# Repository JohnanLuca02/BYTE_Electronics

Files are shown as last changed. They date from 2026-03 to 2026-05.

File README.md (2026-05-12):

# BYTE_Electronics
Repository for everything concerning the electronics (PCB, Electrical schemes, BOM, ...) of the robot dog project of the AiTeam called BYTE.

**READ BEFORE STARTING TO WORK**

**Github workflow:**

*ALWAYS* work on your own branch
1) Check that you're in the correct branch:
   - git branch --all
       - if your branch is highlated in *green*, you can go to step 2)
       - if your branch is highlated in *red*, follow the next steps:
           - git fetch --all
           - git checkout [*name of your branch*]
     
2) Once you're in the right branch, *always* start pulling the changes:
   - git pull 
3) Often save your progress:
   - git add .
   - git commit -m "[*Message describing the changes made*]"
4) At the end of your session, ore once you're happy with your work, push your progress on the repo:
   - git push
  
**FOR EASYEDA2KICAD PLUG-IN**

easyeda2kicad --full --lcsc_id [LCSC CODE] --output .

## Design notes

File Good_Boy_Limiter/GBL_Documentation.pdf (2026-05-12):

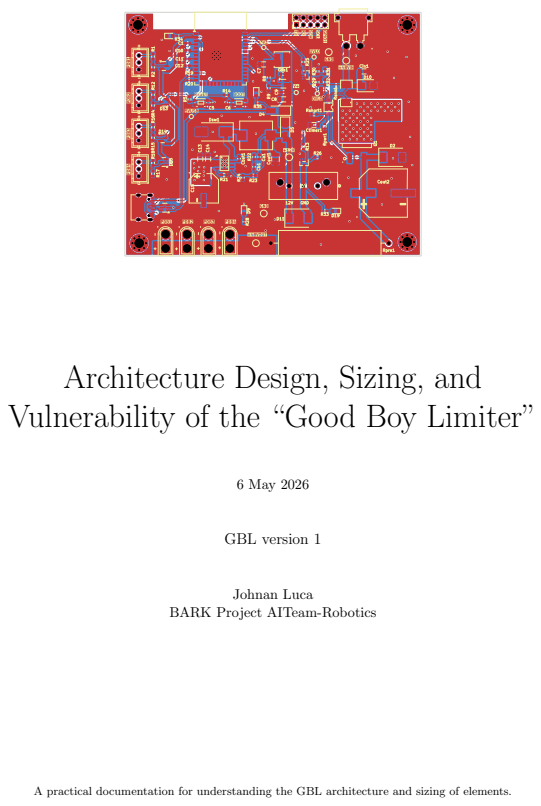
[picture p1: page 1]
6 May 2026; GBL version 1; Johnan Luca

Architecture Design, Sizing, and
Vulnerability of the “Good Boy Limiter”

BARK Project AITeam-Robotics

A practical documentation for understanding the GBL architecture and sizing of elements.

## Contents

1 Abstract and System Overview | 2
2 Power Architecture: Relay Versus Solid-State | 2
3 Analysis and Sizing of the Pre-Charge Dynamics | 3
4 In-Rush Controller (LM5069) Analysis and Sizing | 4

4.4 Power Limit Sizing (PF ET(LIM)

5 Thermal Management and MOSFET Safe Operating Area (SOA) | 7
6 Thermal Limitations: Analyzing the 50 Ω Power Resistor | 7
7 Control Logic, System Security, and the Software Timeout | 8
8 Auxiliary Power Supply: LM5013 DC-DC Converter | 9
9 Power Supply Logic and 3V3 Selector (SY8120B and Case Control) | 10
10 LEDs | 12
11 Conclusion and Recommendations | 13
12 Next Steps for future iterations | 13
13 Annexes | 13
14 References | 17

## 1 Abstract and System Overview

The design of high-power DC distribution networks frequently encounters the engineering challenge of managing massive capacitive loads during the initial charging phase. The “Good Boy Limiter” (GBL) represents an hybrid power management and in-rush current control architecture specifically designed to address these challenges within a 48 V DC ecosystem.
The main problem addressed by the GBL architecture is the safe charge and continuous operation of a downstream load characterized by a really large input capacitance. Specifically, the system must interface with a bulk bus capacitance (Ctot) of 7920 µF, which is physically realized through a distributed 4 × 6 matrix of 330 µF electrolytic capacitors. Furthermore, the system is designed to support a substantial nominal operating current of 260 A, although it is currently constrained to a 120 A limit for safety reasons.
Attempting to directly connect a 48 V stiff voltage source to an uncharged 7920 µF capacitor bank results in an instantaneous ”in-rush” current theoretically limited only by the Equivalent Series Resistance (ESR) of the capacitors and the parasitic inductance of the interconnecting cables. In practical terms, this transient current can easily exceed several thousands of amperes. Such catastrophic current spikes induce severe electromagnetic interference (EMI), trigger upstream power supply overcurrent protections, and instantly weld the contacts of mechanical relays due to localized plasma arcing.
To resolve these conflicting requirements, the GBL employs a mixed relay/solid-state architecture. A heavy-duty mechanical external relay (actuated via a 12 V coil) serves as the primary conduction path during nominal steady-state operation. In parallel, a highly controlled solid-state pre-charge circuit, orchestrated by the Texas Instruments LM5069-2 hot-swap controller and an STMicroelectronics STB15810 MOSFET, governs the initial energization phase.
This report provides an exhaustive analysis of the pre-charge dynamics, focusing on the mathematical sizing of the LM5069-2 control parameters. It critically examines the thermal paradigm shift achieved by the inclusion of a series limiting resistor, assesses the Safe Operating Area (SOA) of the selected MOSFET, and documents the role of the ESP32-S3 microcontroller in mitigating topological safety vulnerabilities.

## 2 Power Architecture: Relay Versus Solid-State

High-current DC power distribution systems inherently suffer from the physical limitations of their switching elements. The architectural decision to utilize a hybrid system in the Good Boy Limiter is grounded in fundamental power dissipation physics.

### 2.1 The Limitations of Pure Solid-State Switching

In a hypothetical pure solid-state architecture managing the full 260 A nominal current, the conduction losses would be to high. Even utilizing state-of-the-art power MOSFETs exhibiting an ultra-low drain-to-source on-resistance (RDS(on)

) of 1 mΩ, the continuous power dissipation (Ploss) would be substantial. According to Joule’s law:

Ploss = I

2 × RDS(on) = (260 A)² × 0.001 Ω = 67.6 W | (1)

Dissipating 67.6 W of pure thermal energy on a printed circuit board (PCB) requires massive copper planes, extensive thermal via arrays, large extruded aluminum heatsinks, and mandatory active forced-air cooling. This increases volumetric footprint, acoustic noise, and overall system failure rates.

### 2.2 The Limitations of Pure Mechanical Switching

Vice-versa, a purely mechanical relay architecture offers micro-ohm contact resistance, virtually eliminating steady-state thermal dissipation. However, mechanical relays are physically incapable of closing into an uncharged 7920 µF capacitive bus at 48 V. As the relay contacts physically approach one another during closure, the dielectric breakdown voltage of the microscopic air gap is exceeded. This initiates a high-energy plasma arc. The thousands of amperes of in-rush current flowing through this plasma instantly melt the contact plating, leading to contact welding and permanent failure of the relay.

### 2.3 The Hybrid Resolution

The GBL architecture resolves this dichotomy via a parallel power path topology:

- The Solid-State Pre-Charge Path: Engaged first, this path utilizes a series-pass Nchannel MOSFET (STMicroelectronics STB15810) and a 50 Ω wirewound power resistor (EWWR0010J50R0T9) to strictly limit the transient charging current. The capacitors are charged safely over a calculated time domain.
- The Main Relay Path: Engaged only when the ESP32-S3 microcontroller verifies that the bus voltage has reached the nominal source voltage. Because the voltage differential (∆V ) across the relay contacts is near zero, the corresponding current during closure is zero. Closing the relay under this Zero-Voltage Switching (ZVS) entirely eliminates arcing, preserving contact longevity. Once the relay is closed, the solid-state path is disabled.

## 3 Analysis and Sizing of the Pre-Charge Dynamics

The pre-charge network is mathematically modeled as a first-order ideal RC circuit. The primary system parameters dictate a DC source voltage (VIN ) of 48 V, a total bus capacitance (Ctot) of 7920 µF, and a physical current-limiting series resistance (Rpre) of 50 Ω.

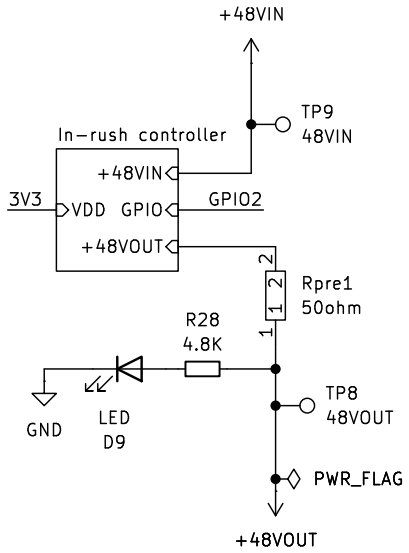
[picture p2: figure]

Figure 1: Detail of the solid-state pre-charge topology. The 50 Ω resistor RP RE1 dominates the branch impedance, physically limiting the maximum current to 0.96 A regardless of the state of the LM5069 controller.

### 3.1 Peak In-Rush Current Constraint

The theoretical peak current (Ipeak) occurs instantaneously at t = 0, assuming the capacitor bank is fully discharged (VC = 0 V). The peak current is defined by Ohm’s Law across the series resistor:

Ipeak =

VIN

Rpre

=

48 V
50 Ω = 0.96 A | (2)

By actively restricting the peak current to a mere 0.96 A, the GBL architecture completely eliminates the stress on the upstream 48 V power supply. The upstream source perceives the startup event as a negligible, highly controlled 46 W load rather than a multi-kilowatt short circuit.

### 3.2 Time Constant and RC Charging Profile

The exponential voltage charging profile of the capacitor bank is governed by the RC time constant (τ ), which dictates the temporal response of the circuit:

τ = Rpre1 × Ctot = 50 Ω × 0.00792 F = 0.396 s | (3)

The bus voltage as a function of time, VC(t), is defined by the standard step-response differential equation solution:
VC(t) = VIN
1 − e

−t
τ

= 48
1 − e

−t

0.396
(4)

In standard engineering practice, a capacitor is considered functionally charged at 3τ (95.0% of VIN ) and fully charged at 5τ (99.3% of VIN ).
We can calculate the exact time required to reach the 95% threshold (45.6 V):
t95% = 3 × τ = 3 × 0.396 s = 1.188 s | (5)

Furthermore, the time required to reach the 99% threshold (47.5 V):

t99% = 5 × τ = 5 × 0.396 s = 1.980 s | (6)

These timing calculations define the minimum operational window required before the ESP32-S3 firmware can safely command the main mechanical relay to close. Actuating the relay before 1.188 s would risk residual arcing due to a significant remaining voltage differential.

### 3.3 Energy Transfer Thermodynamics

The total energy transferred from the 48 V source to fully charge the capacitor bank is derived from the energy stored in the electric field of the capacitors:

Ecap =

1
2

CtotV

2
IN =

1
2
× 0.00792 F × (48 V)² = 9.1238 J | (7)

A fundamental principle of thermodynamics in RC charging circuits dictates that an exactly equal amount of energy is dissipated as heat within the resistive elements of the charging path. Therefore, regardless of the charging speed, exactly 9.12 J of thermal energy is deposited into the 50 Ω wire-wound resistor during every startup sequence. This will be critically analyzed in Section 6.

## 4 In-Rush Controller (LM5069) Analysis and Sizing

The Texas Instruments LM5069-2 operates as the gate driver and primary hardware safety controller for the solid-state pre-charge branch.
The following subsections detail the mathematical sizing of its internal thresholds.

### 4.1 Undervoltage Lockout (UVLO) Sizing

The UVLO pin ensures the controller only activates when the input bus is stable and possesses sufficient voltage to properly drive the downstream loads. The LM5069 possesses a precise internal comparator with an enable threshold of 2.5 V. To prevent rapid ON/OFF oscillation (chattering) when the input voltage fluctuates near the threshold, the IC utilizes an internal 21 µA current source to provide a programmable hysteresis.
The GBL schematic defines a dedicated UVLO resistive divider utilizing R25 = 143 kΩ as the top resistor and R30 = 10 kΩ as the bottom resistor connected to ground.
The rising input threshold voltage (VUVLO RISE) at which the controller enables the pre-charge sequence is calculated as:

VUVLO RISE = VREF ×

R25 + R30

R30

= 2.5 V ×

143 kΩ + 10 kΩ
10 kΩ | = 38.25 V | (8)

Once the input voltage exceeds 38.25 V, the 21 µA internal current source activates and flows out of the UVLO pin, through the bottom resistor R30, effectively raising the pin voltage. This creates the hysteresis voltage (VUVLO HYS), which is dictated by the current source acting upon the top resistor R25:

VUVLO HYS = IHY S × R25 = 21 µA × 143 kΩ = 3.003 V | (9)

The falling threshold voltage (VUVLO FALL), where the controller will abort the sequence due to a sagging input bus, is therefore:

VUVLO FALL = VUVLO RISE − VUVLO HYS = 38.25 V − 3.003 V = 35.247 V | (10)

Therefore, the pre-charge sequence is hardware-locked until the input voltage is a steady 38.25 V, and it possesses a robust 3 V noise margin before shutting down at 35.24 V.

### 4.2 Overvoltage Lockout (OVLO) Sizing

Similarly, the OVLO pin protects the downstream systems from catastrophic input voltage surges, such as load-dump events or incorrect power supply connections. To maintain precise and independent control over the overvoltage threshold, the GBL schematic utilizes a separate, dedicated divider string: R32 = 210 kΩ as the top resistor and R29 = 10 kΩ as the bottom resistor.
The rising overvoltage cutoff threshold (VOVLO RISE) is calculated using the same 2.5 V internal reference:

VOVLO RISE = VREF ×

R32 + R29

R29

= 2.5 V ×

210 kΩ + 10 kΩ
10 kΩ | = 55.00 V | (11)

The OVLO pin also features a 21 µA hysteresis current source. The hysteresis voltage is:

VOVLO HYS = IHY S × R32 = 21 µA × 210 kΩ = 4.410 V | (12)

The falling recovery threshold (VOVLO FALL), where the system permits operation to resume after an overvoltage event clears, is:

VOVLO FALL = VOVLO RISE − VOVLO HYS = 55.00 V − 4.41 V = 50.59 V | (13)

The hardware overvoltage cutoff is situated at 55.00 V. This provides adequate operational margin above the nominal 48 V state, while strictly protecting downstream components from transient degradation.

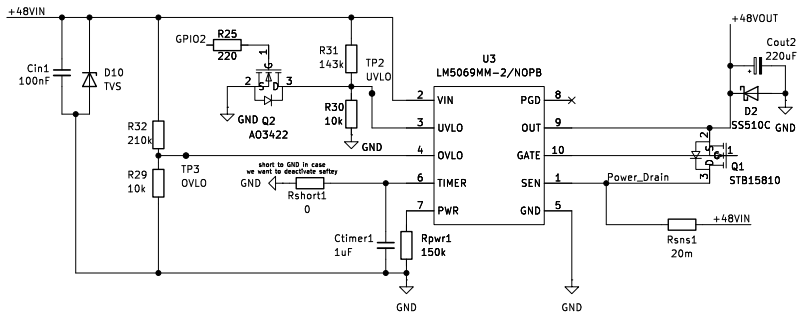
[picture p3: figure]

Figure 2: Schematic of the independent resistive dividers for the undervoltage (R25, R30) and overvoltage (R32, R29) thresholds. The use of two separate networks ensures clear and independent hysteresis for the operating windows at 38.25 V and 55.00 V.

### 4.3 Hardware Current Limit (ILIM ) and Rsns1 Sizing

The standard operational mode of the LM5069 relies on sensing the voltage drop across a precision shunt resistor (RSENS1) placed directly between the VIN and SENSE pins. If the load current increases such that the voltage across the sense resistor reaches 55 mV, the LM5069 limits the current by dynamically adjusting the MOSFET gate voltage.
In the GBL design, a value for RSENS1 = 20 mΩ is utilized. The absolute hardware current limit is established mathematically as:

ILIM =

VSNS(th)

RSENS1

=

55 mV
20 mΩ = 2.75 A | (14)

### 4.4 Power Limit Sizing (PF ET(LIM))

To protect the external MOSFET from violating its Safe Operating Area (SOA) during linear mode regulation, the LM5069 allows the maximum allowable power dissipation of the FET to be programmed via the PWR pin. The LM5069 monitors the VDS of the MOSFET by comparing the SENSE pin and the OUT pin.
This limit is set using an external resistor (RPW R1) connected to the PWR pin. The schematic indicates RPW R1 = 150 kΩ.
The formula correlating the programmable power limit to the sense resistor and the PWR resistor is provided by Texas Instruments as:

PF ET(LIM) =

RPW R1
1.25 × 10⁵ × RSENS1

=

150, 000 Ω
1.25 × 10⁵ × 0.020 Ω = 60 W | (15)

The hardware is theoretically configured to throttle the MOSFET gate if it detects the MOSFET is dissipating more than 60 W of heat. However, the presence of the 50 Ω resistor ensures the MOSFET never dissipates anywhere near 60 W. This will be proven in Section 5.

### 4.5 Fault Timer Duration (tF AULT )

The fault timeout allows the system to ride through brief, acceptable transient over-currents without nuisance tripping, but ensures the MOSFET is definitively shut down if a fault persists long enough to threaten the system. The timing is dictated by an external capacitor CT IMER1 = 1 µF connected to the TIMER pin.
The typical duration before a fault is declared and the gate is pulled low is defined by the equation:

tF AULT = CT IMER1 ×

vtimer,typ

itimer,typ

= 1 × 10⁻⁶ F × 4.7 × 10⁴ = 0.047 s = 47 ms (16)

The specific LM5069-2 variant utilized in this design features an Auto-Retry mechanism. If the controller were to enter a current or power limit regulation state for longer than the 47 ms timer, the device would shut down the MOSFET, run through an extended internal cool-down cycle (dictated by the same capacitor), and then attempt to restart the process automatically. However, as established, the controller is physically prevented from ever entering the regulation state due to the 50 Ω resistor.

## 5 Thermal Management and MOSFET Safe Operating Area

## (SOA)

The defining architectural characteristic of the GBL pre-charge circuit is the intentional shifting of the massive thermal dissipation burden away from the semiconductor lattice of the STB15810 MOSFET and onto the robust, passive wirewound resistor.

### 5.1 The STB15810 MOSFET in Deep Saturation

In the Good Boy Limiter architecture, the presence of the 50 Ω resistor physically restricts the maximum current to 0.96 A. Because 0.96 A is vastly lower than the LM5069’s 2.75 A current regulation threshold, the LM5069’s internal high-side charge pump continues to pump unabated. It fully enhances the MOSFET gate, raising VGS to its maximum value (typically 10 V to 12 V above the source). This pushes the MOSFET completely out of the linear region and deep into the ohmic region (saturation).
The STB15810 is a heavily over-specified 100 V, 110 A device utilizing advanced STripFET™ F7 trench gate technology, boasting an ultra-low RDS(on) of 3.9 mΩ typical and 7 mΩ absolute maximum.
Assuming the worst-case scenario at maximum operating junction temperature where RDS(on) = 7 mΩ, the peak power dissipated by the MOSFET during the absolute highest current flow of the pre-charge phase (0.96 A at t = 0) is simply calculated using Joule’s law for a pure resistance:

PMOSF ET(peak) = I

2

peak × RDS(on) = (0.96 A)² × 0.007 Ω = 0.0064 W = 6.4 mW (17)

Dissipating a mere 6.4 mW means the STB15810 will experience absolutely zero measurable thermal rise above ambient temperature. The device remains entirely safe, utterly immune to the Spirito effect, and operates infinitely deep within the safest bounds of its DC SOA curve. From the perspective of thermal stress, the MOSFET acts as a perfect wire.

## 6 Thermal Limitations: Analyzing the 50 Ω Power Resistor

Because the MOSFET acts as a near-perfect conductor, the 50 Ω wirewound resistor assumes basically 100% of the thermal load during the pre-charge event.
During the exact moment of turn-on (t = 0), the capacitor bank acts as a short circuit, meaning the entire 48 V source is dropped across the resistor. The instantaneous peak power dissipation is:

PRESIST OR(peak) =

V

2
IN
Rpre

=

(48 V)²
50 Ω = 46.08 W | (18)

The selected component, EWWR0010J50R0T9, is a wirewound power resistor rated for 10 W of continuous steady-state power. Operating a 10 W rated resistor at 46.08 W could appears as a design error; however, it is permissible because pre-charging is a highly transient pulse event, not a steady-state condition.
As calculated in Equation (7), the total energy deposited into the resistor over the entire 1.5 to 2.0 second charging curve is strictly bounded to 9.12 J. Wirewound resistors are specifically constructed by winding a resistive alloy wire around a dense ceramic core. This ceramic core possesses a significant thermal mass. During a short 2-second pulse, the heating is largely adiabatic, the energy is absorbed directly into the thermal mass of the ceramic core, resulting in a moderate, entirely safe transient temperature rise.
The critical operational limitation here is duty cycle: the system must not be commanded to repeatedly toggle the pre-charge sequence in rapid succession. Sufficient cool-down time (several seconds) must be enforced by the ESP32 software to allow the ceramic core to shed this thermal energy to the ambient environment.

## 7 Control Logic, System Security, and the Software Timeout

While the delegation of the current-limiting role to a passive 50 Ω resistor safely protects the MOSFET, it simultaneously creates a critical vulnerability within the hardware protection layers of the LM5069. This vulnerability necessitates the implementation of an active software safety supervisory system via the ESP32-S3 microcontroller.

### 7.1 The “Hardware Blind Spot” during a Hard Short

Consider a catastrophic operational scenario: a dead short circuit directly to ground exists on the 48 V output bus (e.g., a crushed cable or a failed downstream component) before the system is turned on.
When the ESP32 initiates the pre-charge sequence, the 50 Ω resistor performs its physical duty and limits the fault current:

Ifault =

48 V
50 Ω + 0.020 Ω + 0.007 Ω
≈ 0.96 A | (19)

Because the fault current (0.96 A) is significantly lower than the LM5069 hardware current limit threshold (2.75 A), the LM5069 internal current comparator is never triggered. Furthermore, because the 50 Ω resistor is dropping nearly the entire 48 V, the voltage at the SENSE pin is roughly 0 V, and the VDS across the MOSFET is negligible (a few millivolts). Consequently, the power limit comparator (PLIM = 60 W) is also completely blind to the fault.
The Catastrophic Result: The LM5069 views the dead short circuit as a completely normal, healthy operating condition. The internal 47 ms fault timer (CT IMER) never begins counting. The hardware safety system will remain engaged indefinitely, forcing the 10 W wirewound resistor to continuously dissipate 46.08 W. Within a matter of seconds, the resistor will violently exceed its thermal degradation limits, resulting in extreme overheating, outgassing, potential ignition of surrounding components, and ultimately an open-circuit failure.

### 7.2 The ESP32-S3 Software Timeout Mitigation

To permanently resolve this dangerous topological vulnerability, the ESP32-S3 microcontroller is tasked with monitoring the dynamic health of the pre-charge process via the dedicated Voltage Sensing Modules.

Figure 3: Schematic diagram of the V Sensing modules used by the ESP32 to read the bus voltage. Note the resistor dividers connected to the BAT54S diodes, which are essential for protecting the microcontroller’s ADC inputs from transient overvoltages.

The ESP32 reads the intermediate bus voltage via a resistor divider string (R14 = 10 kΩ, etc.). These inputs are aggressively protected by dual BAT54S Schottky clamping diodes, which prevent the microcontroller’s sensitive ADC pins from exceeding the 3.3 V logic supply limit even during severe transients.
The ESP32 firmware must be programmed to implement a strict, non-blocking state-machine timeout logic:
1. Initiation: The ESP32 asserts the LM5069 EN/UVLO pin HIGH via a GPIO pin to begin the pre-charge sequence. Simultaneously, it initializes an internal hardware software timer (t = 0).
2. Continuous Monitoring: The ADC continuously samples the bus voltage (Vbus) at a high frequency.
3. Success Condition: If Vbus successfully exhibits the standard RC charging curve and exceeds 45 V (approximately 3τ ) within a 1.5 to 2.0 second window, the pre-charge is deemed successful. The ESP32 then commands the main 12 V mechanical relay to close, routing the 260 A capability to the load. Once the relay confirms closure, the solid-state branch is deactivated.
4. Timeout Failure Condition (The Critical Mitigation): If Vbus fails to rise above a minimum safety threshold within 3.0 seconds (a “Timeout of Security”), it is definitive proof of a downstream fault or short circuit absorbing the charge current. The ESP32 must immediately and unconditionally force the EN/UVLO pin LOW. This action forcefully shuts down the LM5069, halting the current flow and saving the 50 Ω resistor from thermal destruction.

This software-defined safety boundary bridges the gap left by the hardware topology, ensuring full system resilience against all modes of failure.

## 8 Auxiliary Power Supply: LM5013 DC-DC Converter

To drive the heavy inductive coil of the main mechanical relay and provide logic-level power to the digital supervision systems, the GBL integrates a high-voltage auxiliary step-down (buck) converter based on the Texas Instruments LM5013DDAR.
The LM5013 steps the primary 48 V distribution bus down to an intermediate 12 V rail. The converter is capable of handling inputs up to 100 V, providing massive immunity against 48 V bus ringing and transients. It operates utilizing a Constant On-Time (COT) architecture. COT control provides exceptional transient load response (essential when slamming a heavy relay coil) and entirely eliminates the need for complex external loop compensation networks (type II or type III compensators), simplifying the PCB layout.

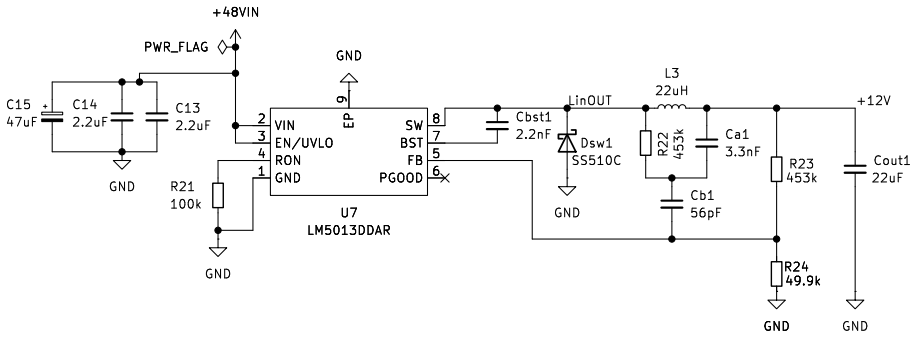
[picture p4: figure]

Figure 4: Topology of the LM5013 step-down converter. The main components are: the 22 µH inductor L3, the bypass diode Dsw1 (SS510C), and the R23/R24 feedback network for precise regulation of the 12 V output.

### 8.1 Feedback Sizing for the 12 V Rail

The output voltage is programmed via a precision resistor divider feeding back into the FB pin. The highly precise internal bandgap reference voltage of the LM5013 is exactly VREF = 1.2 V. The schematic defines the top feedback resistor as RF B1(R23) = 453 kΩ and the bottom resistor connected to ground as RF B2(R24) = 49.9 kΩ.
The nominal output voltage is mathematically derived as:

VOUT = VREF ×

1 +

RF B1

RF B2

= 1.2 V ×
1 +

453 kΩ

49.9 kΩ
(20)
VOUT = 1.2 V × (1 + 9.078) = 1.2 V × 10.078 = 12.09 V | (21)

### 8.2 Core Buck Components and Filtering

The power stage utilizes a low-DCR inductor L3 = 22 µH and an SS510C Schottky freewheeling diode (DSW1). The presence of the external Schottky diode is mandatory for this nonsynchronous topology to provide a path for the inductor current during the MOSFET off-time. The Constant On-Time programming resistor is RON (R21) = 100 kΩ, establishing the nominal switching frequency.
Input voltage ripple and filtering are aggressively handled by dual low-ESR 2.2 µF ceramic capacitors (C13, C14) plus a larger 47 µF bulk capacitor (C15). This network attenuates highfrequency switching noise, preventing the buck converter from injecting harmonic distortions back into the main 48 V distribution bus. A secondary step-down stage (utilizing the SY8120B buck converter) subsequently drops this intermediate 12 V to a highly regulated 3.3 V rail to power the ESP32-S3 microcontroller and its associated sensitive analog peripherals.

## 9 Power Supply Logic and 3V3 Selector (SY8120B and Case Control)

The ESP32-S3 and the analog logic arrays require a stable, low-noise 3.3V power rail. To ensure the microcontroller remains active and functional under multiple operating conditions, such as during initial programming via a PC (USB power), standalone operation from external logic batteries, or standard nominal operation connected to the main 48V bus, a specialized “3V3 Selector” architecture is implemented.

Figure 5: Schematic diagram of the “3V3 Selector” module based on the SY8120B synchronous buck converter. Note the OR-gate diode configurations (D4 and D5) for transparent switching between the USB power supply and the 12V bus, and the R10/R11 feedback divider for precise regulation to 3.3V.

### 9.1 Power Source OR-ing Network and Operational Scenarios

The input to the 3.3V regulation stage (Vin) is sourced dynamically via a passive diode OR-ing network. This network prevents reverse-current back-feeding and allows the system to autonomously draw power from the most viable source without logic interruption. The system relies on two SS34 Schottky diodes (D4 and D5) which feature a low forward voltage drop (Vf ≈ 0.4V at nominal logic currents).The architecture supports three distinct operational scenarios:

- Case 1: PC Configuration Only (No Main Battery Connected).
When the GBL is completely disconnected from the 48V high-voltage bus (no XT30 battery connected) and plugged into a host PC via the USB-C connector, the cable supplies +5VUSB. Diode D4 becomes forward-biased. The internal node Vin reaches approximately 4.6V (5V − Vf(D4)). Because the SY8120B regulator has a minimum operational input threshold of 4.0V, it successfully activates, generating the 3.3V rail. This allows the ESP32 to be programmed, flashed, or debugged safely on a workbench without exposing the user to high-voltage hazards.
- Case 2: Main Battery / 48V Bus Nominally Connected.
During standard operation, the main power source (e.g., a 48V battery pack) is connected to the XT30 connectors (CN1). The upstream LM5013 buck converter actively steps the 48V down to the intermediate +12V rail. This 12V potential reaches the anode of diode D5. D5 becomes forward-biased, pulling the Vin node to approximately 11.6V (12V − Vf(D5)). The SY8120B easily accepts this input (rated up to 18V maximum) and drops it to 3.3V.
- Case 3: Both Main Battery and PC USB Connected.
This is the most critical cross-power scenario. If a user connects the USB-C cable for telemetry while the 48V bus is fully live, the OR-ing network automatically resolves the power conflict. The anode of D5 sits at +12V, while the anode of D4 sits at +5VUSB. Because the cathodes of both diodes are tied together at the Vin node, D5 will strongly conduct and pull the Vin node up to 11.6V. Consequently, the +11.6V at the cathode of

D4 is significantly higher than the +5V at its anode. Diode D4 becomes heavily reversebiased and stops conducting completely.
Result: The logic array draws zero power from the host PC’s USB port, protecting the laptop’s motherboard and ensuring the ESP32 is powered exclusively by the main battery line, while keeping the communication lines active for interfacing the MCU.

### 9.2 SY8120B Synchronous Buck Converter Sizing

Unlike the LM5013, the SY8120B is a synchronous buck converter. It integrates both the high-side and low-side switching MOSFETs internally. These internal switches boast very low RDS(on) characteristics (145 mΩ top / 135 mΩ bottom), minimizing conduction losses and entirely eliminating the need for an external Schottky freewheeling diode.
The output voltage is programmed by the external resistor divider connected to the feedback (FB) pin. The internal bandgap reference voltage of the SY8120B is VREF = 0.6V.Utilizing the designated top resistor R10 = 100 kΩ and the bottom resistor R11 = 22 kΩ, the nominal output voltage is derived using the standard feedback formula:

VOUT = VREF ×

1 +

R10

R11
= 0.6 V ×
1 +

100 kΩ

22 kΩ
= 3.327 V | (22)

The calculated 3.327V output provides a regulated logic-level rail for the ESP32-S3. An external pull-up resistor R8 = 100 kΩ connects the EN (Enable) pin directly to the input voltage node (Vin), ensuring the regulator automatically initiates switching the millisecond a valid power source (USB or Battery) is applied via the OR-ing networkr.

## 10 LEDs

### 10.1 LED’s Resistors Sizing

To light an LED from a power rail, you simply place the LED in series with a current-limiting resistor across the rail and ground. You must calculate the correct resistance (R) using Ohm’s Law for preventing the LED to burn out:

R =

Vrail − Vf
If

(23)

- Vrail: The voltage of your power rail (e.g., 3.3V, 5V, 12V).
- Vf : The Forward Voltage of the LED (typically 1.8V for Red, 3.2V for Blue/White).
- If : The Forward Current you want (typically 2mA to 20mA).

### 10.2 GBL’s LEDs Color Code

- RED: +48V Pre-charge power rail is ON
- YELLOW: +3V3 power rail is ON
- GREEN: Relay is closed
- BLUE: +5USB power rail is ON
- ORANGE: +12V rail is ON

## 11 Conclusion and Recommendations

The “Good Boy Limiter” architecture represents a possible solution to the challenge of managing massive capacitive loads in high-current DC environments. By utilizing a mixed-topology parallel design, it combines the zero-loss continuous conduction capabilities of a mechanical relay with the non-destructive startup characteristics of a solid-state pre-charge circuit.
The sizing of the Texas Instruments LM5069-2 components is mathematically made. The selected resistor dividers establish 38.25 V and 55.00 V operational voltage lockouts, ensuring the system only operates within a safe 48 V nominal window. The absolute hardware current limit is determinate by RSENS1 at 2.75 A.
Furthermore, the decision to utilize a 50 Ω series power resistor shields the STB15810 MOS-FET from the destructive Safe Operating Area (SOA) stresses typically associated with linearmode hot-swap events. By pushing the MOSFET deep into saturation, its thermal load is reduced to a negligible 6.4 mW, transferring the energy entirely to the adiabatic mass of the wirewound resistor.
Therefore, it is an absolute, critical project requirement to implement the 3.0 second Software Safety Timeout logic on the ESP32-S3. Without this digital supervisor actively pulling the LM5069 EN pin low upon a failure to charge, the 10 W pre-charge resistor will face inevitable and thermal failure under a continuous 46 W fault load.

## 12 Next Steps for future iterations

- Sizing optimization
- Design a better Solid-State branch

– Better LM5069 safety features

– Charge pump (at least to 48V + VGS(th)

) with VGS = 48V SS

– Gate driver with 48V + VGS(th) and boost converter

- Routing optimization

## 13 Annexes

Complete GBL e-scheme:

# H4 H3 GND

10k 1

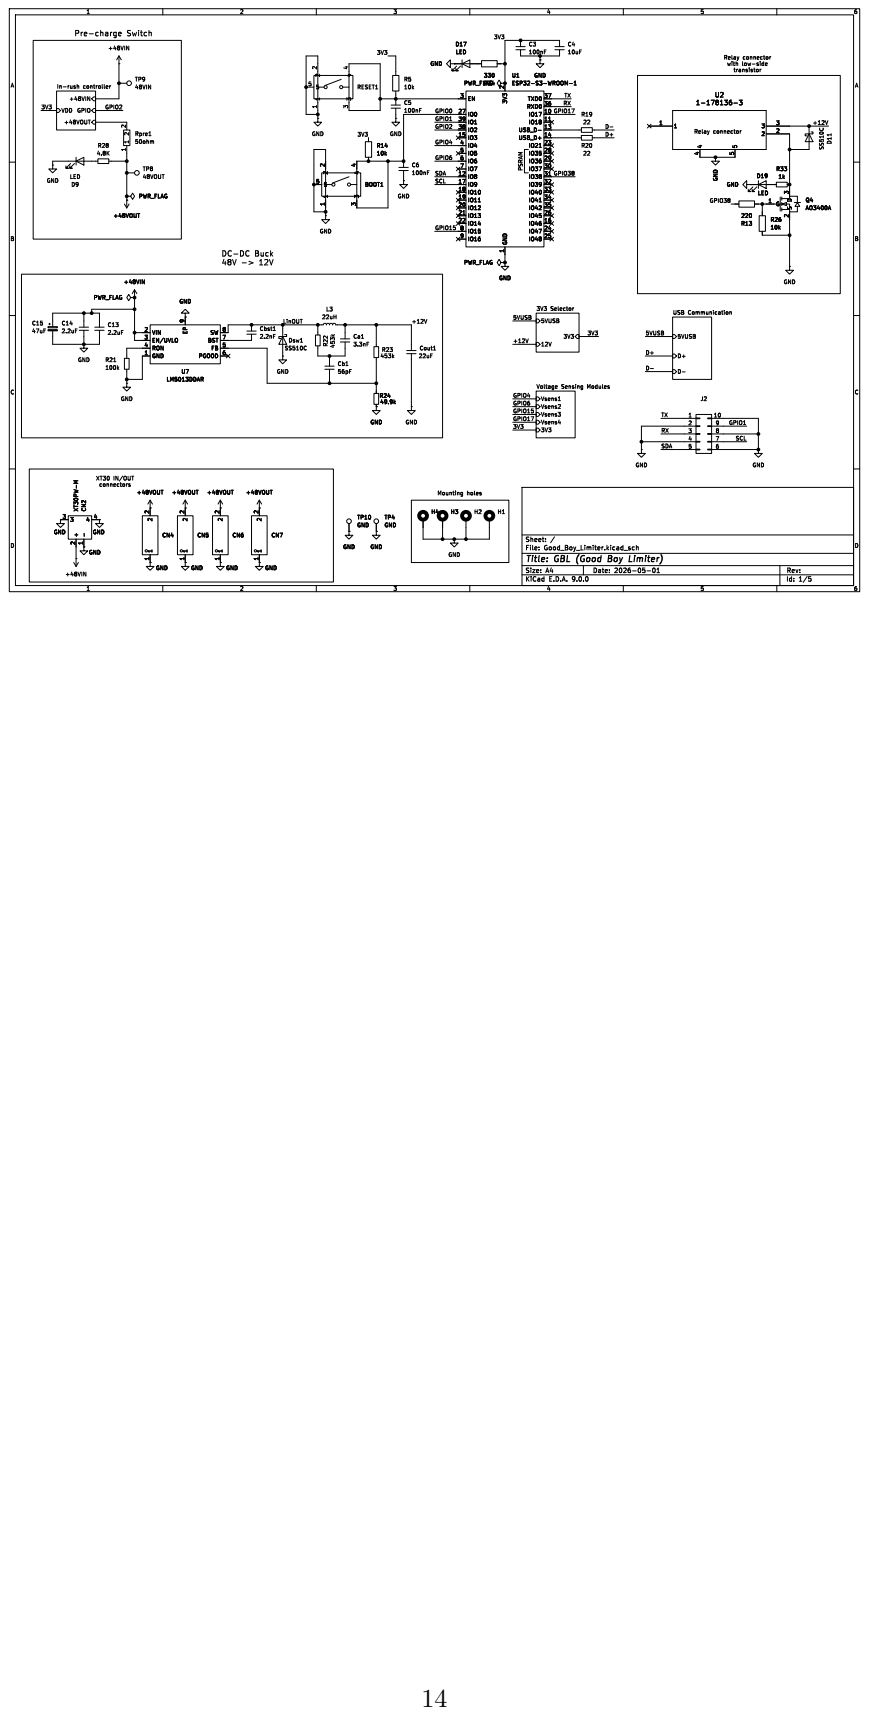
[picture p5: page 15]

transistor DC-DC Buck

3V3 Voltage Sensing Modules VDD

9 SW 8 BST 7 FB 5 PGOOD 6 +48VOUT PWR_FLAG

9 SW 8 BST 7 FB 5 PGOOD 6 U7

Id: 1/5 Title: GBL (Good Boy Limiter) File: Good_Boy_Limiter.kicad_sch Sheet: / Vsens3 Vsens4 Vsens1 Vsens2

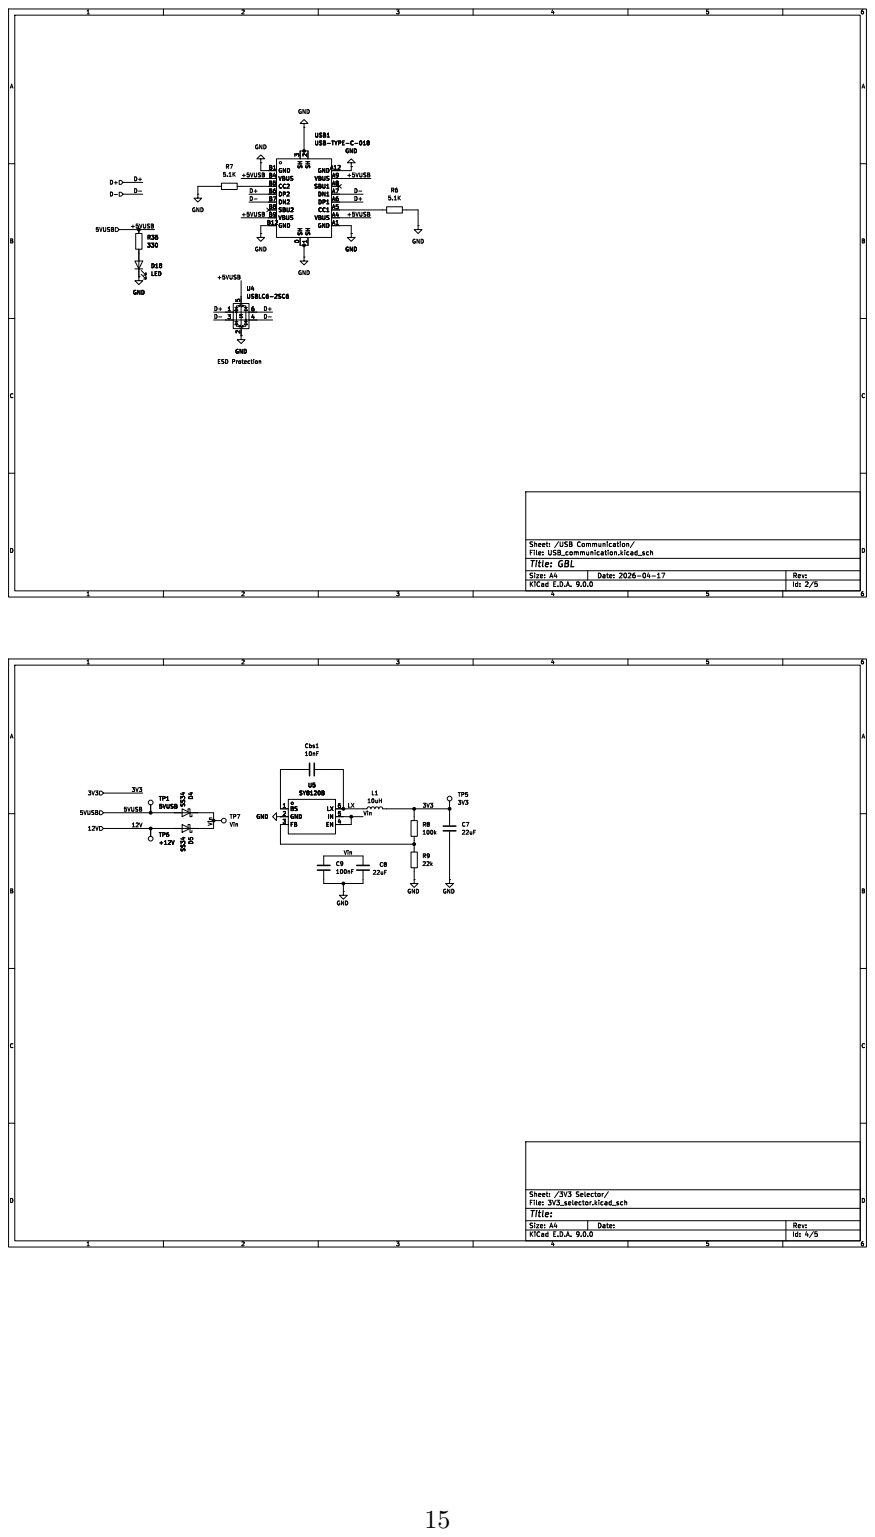
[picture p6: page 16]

1 GNDA12 VBUS A9 SBU1 A8 DN1 A7 DP1 A6 CC1 A5 VBUS A4 GND A1 USB1 USB-TYPE-C-018 GND GND GND GND

File: USB_communication.kicad_sch Sheet: /USB Communication/ GND GND GND GND

Id: 4/5 Title: File: 3V3_selector.kicad_sch Sheet: /3V3 Selector/ L1

# 3 U11 B3B-XH-A C11

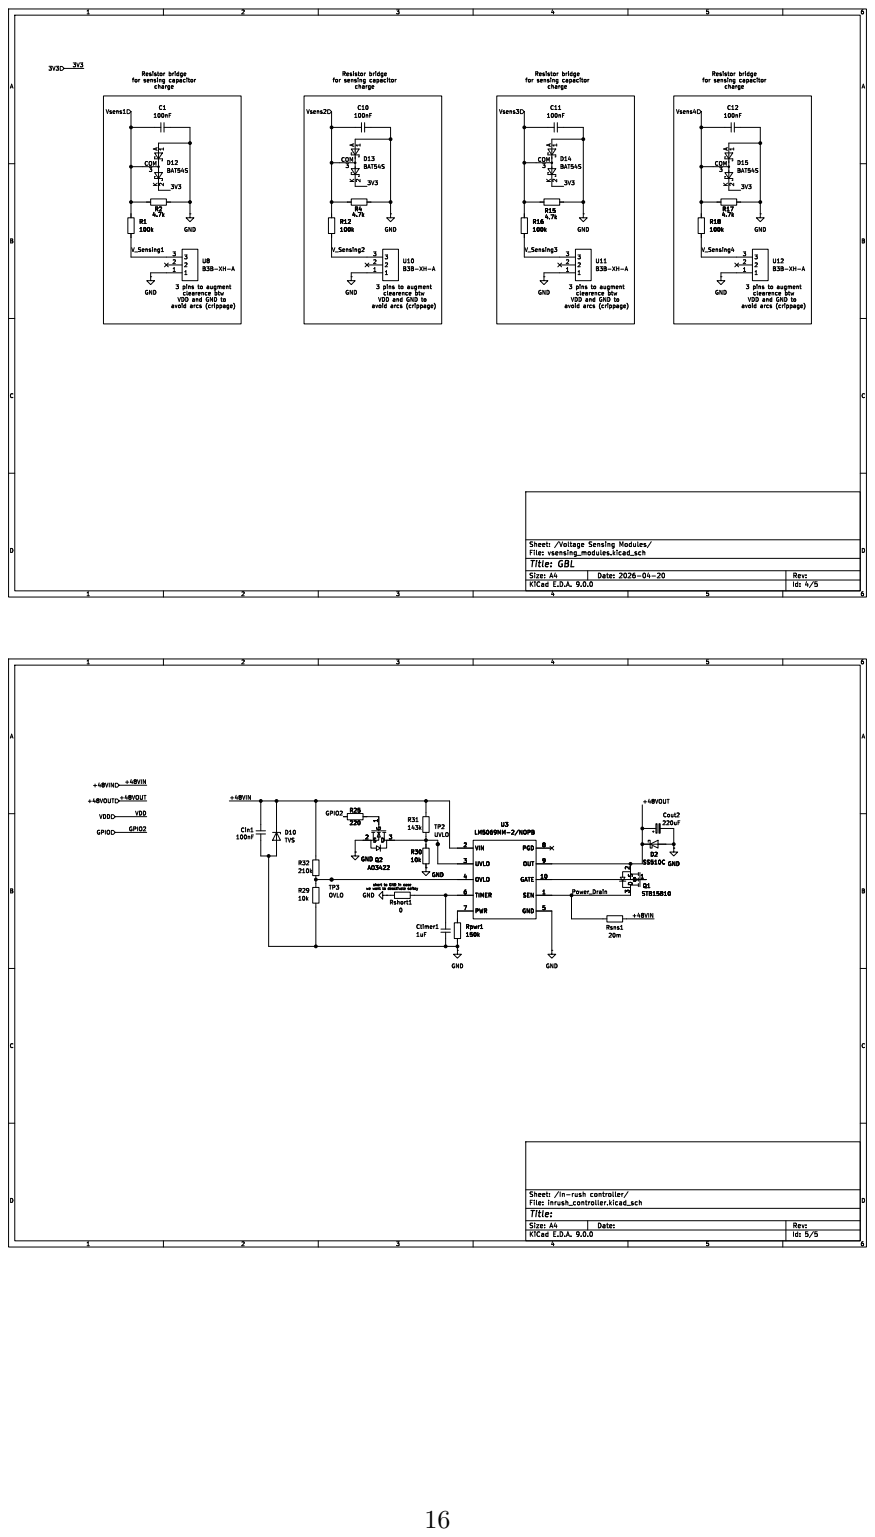
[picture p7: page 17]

VDD and GND to

## 14 References

- Texas Instruments LM5069 Datasheet (https://www.ti.com/lit/ds/symlink/lm5069.pdf)
- Texas Instrument LM5013DDAR Datasheet (https://www.ti.com/lit/ds/symlink/lm5013.pdf)
- STMicroelectronics STB15810 Datasheet (https://file.elecfans.com/web2/M00/24/31/poYBAGGwZlOAfiG4AAkVY6pkKgU639.pdf?STB15810_ST.pdf)
- Slkor SY8120B Datasheet (https://mm.digikey.com/Volume0/opasdata/d220001/medias/docus/6778/5399_SY8120B%20SOT-23-6.PDF)

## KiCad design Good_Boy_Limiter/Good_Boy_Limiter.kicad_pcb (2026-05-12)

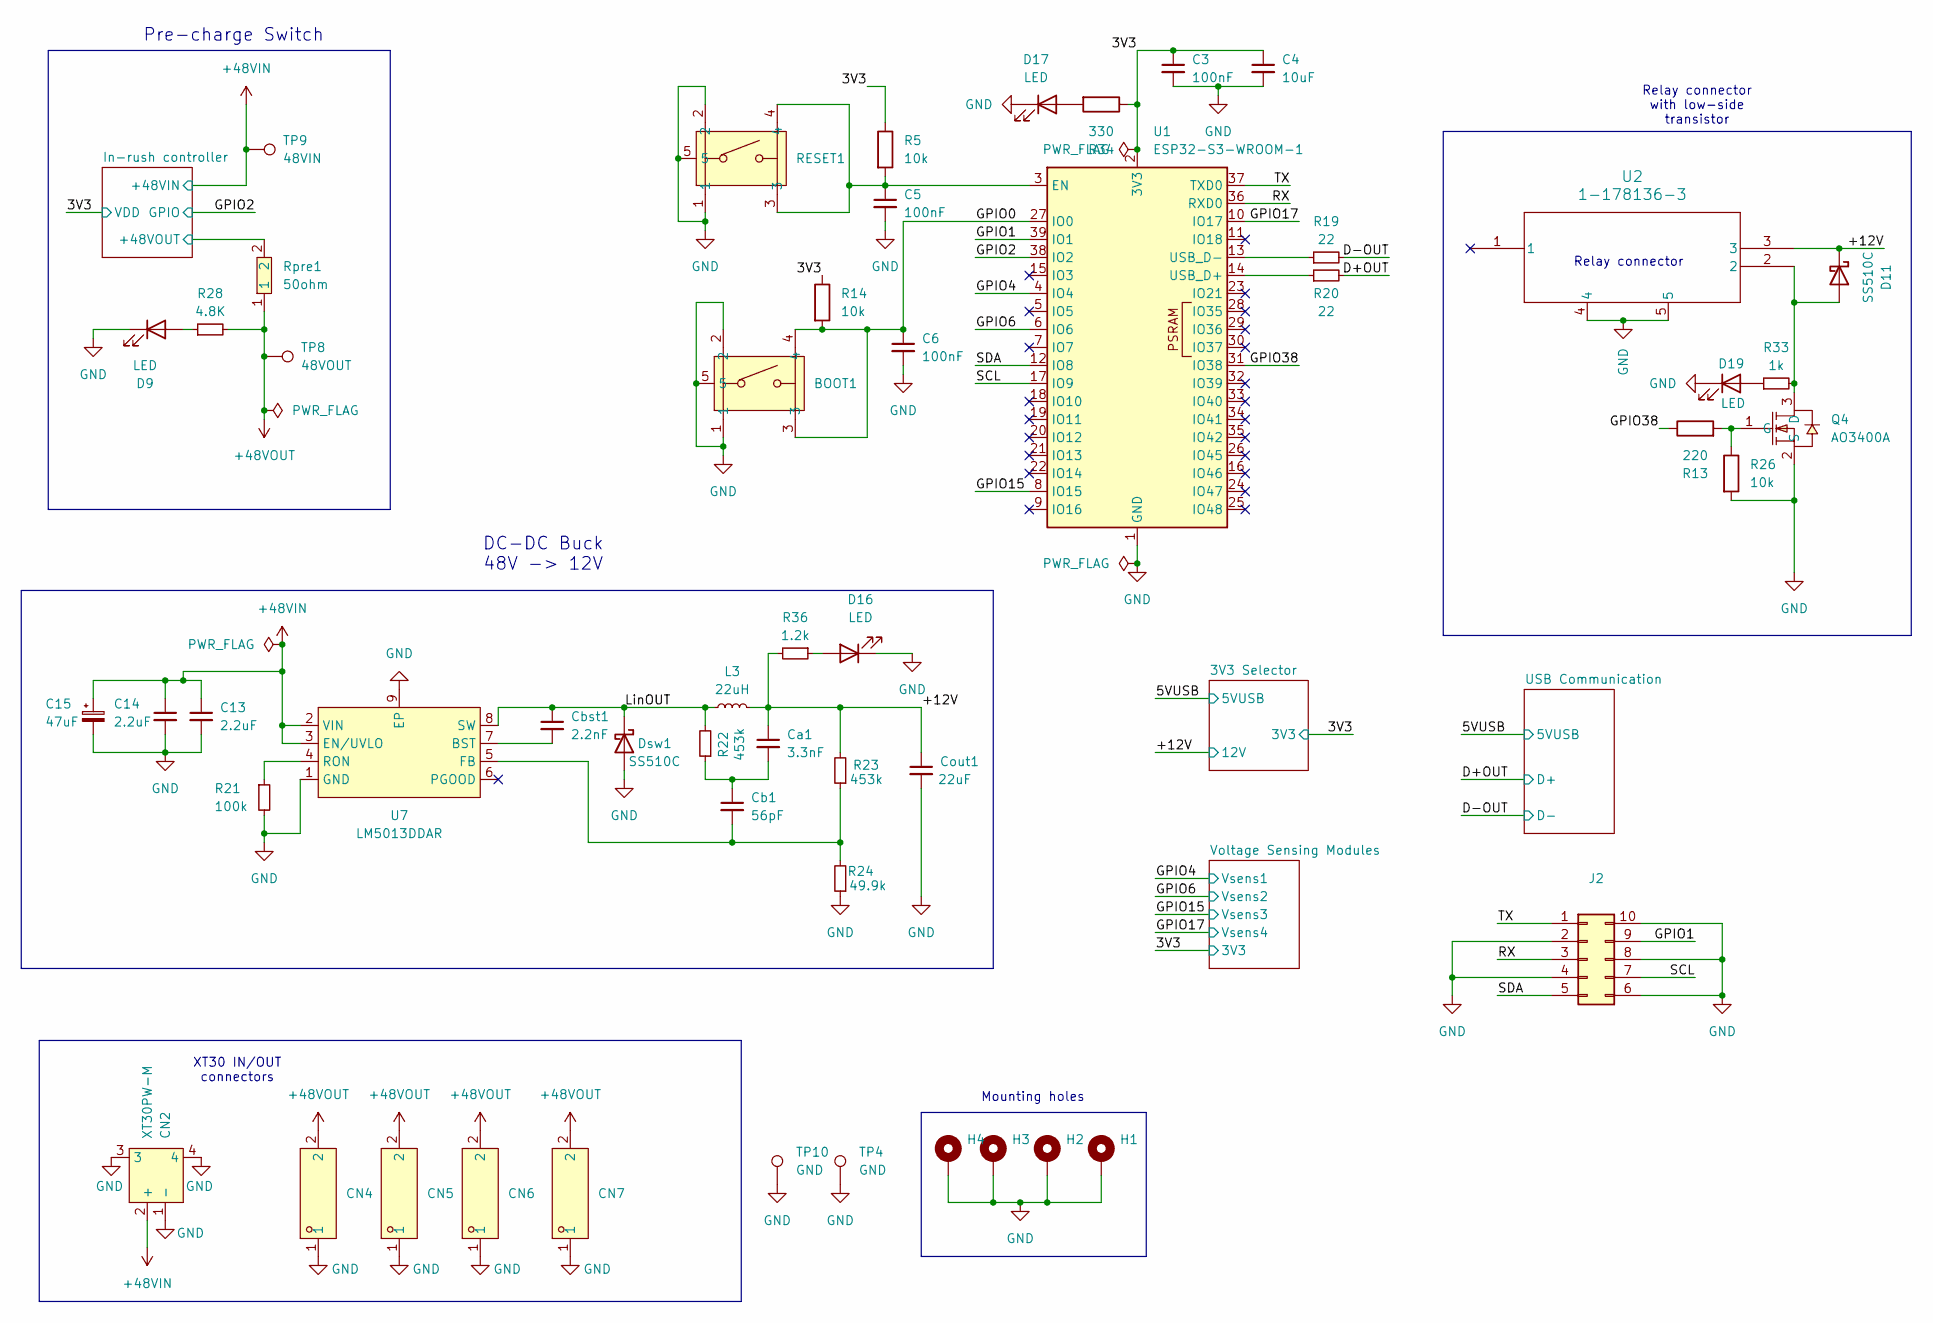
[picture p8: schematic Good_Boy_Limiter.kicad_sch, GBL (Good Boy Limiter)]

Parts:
C3: 100nF; C_0603_1608Metric; LCSC Part C1590
C4: 10uF; C_0603_1608Metric; LCSC Part C1691
C5: 100nF; C_0402_1005Metric; LCSC Part C1525
C6: 100nF; C_0402_1005Metric_Pad0.74x0.62mm_HandSolder; LCSC Part C1525
C13, C14: 2.2uF; C_1206_3216Metric; LCSC Part C577211
C15: 47uF; CAP-SMD_BD10.0-L10.3-W10.3-LS11.0-R-RD; LCSC Part C164068
CN2: XT30PW-M; CONN-TH_XT30PW-M; MPN XT30PW-M30.G.Y; LCSC Part C431092
CN4, CN5, CN6, CN7: XT30UW-F.G.Y; CONN-TH_XT30UW-F.G.Y; MPN XT30UW-F.G.Y; LCSC Part C19268025
Ca1: 3.3nF; C_0603_1608Metric; LCSC Part C1613
Cb1: 56pF; C_0603_1608Metric; LCSC Part C39148
Cbst1: 2.2nF; C_0603_1608Metric; LCSC Part C1604
Cout1: 22uF; C_1210_3225Metric; LCSC Part C5341638
D9: LED; LED_0805_2012Metric_Pad1.15x1.40mm_HandSolder; LCSC Part C2295
D11: SS510C; D_SMC; LCSC Part C19229
D16: LED; LED_0805_2012Metric_Pad1.15x1.40mm_HandSolder; LCSC Part C110371
D17: LED; LED_0805_2012Metric_Pad1.15x1.40mm_HandSolder; LCSC Part C2296
D19: LED; LED_0805_2012Metric_Pad1.15x1.40mm_HandSolder; LCSC Part C2297
Dsw1: SS510C; D_SMC_Handsoldering; LCSC Part C19229
H1, H2, H3, H4: MountingHole_Pad; MountingHole_3.2mm_M3_Pad_Via
J2: Extra General Pins; PinHeader_2x05_P2.54mm_Vertical
L3: 22uH; IND-SMD_L11.5-W10.0; LCSC Part C149546
Q4: AO3400A; SOT-23-3_L2.9-W1.3-P1.90-LS2.4-BR; MPN AO3400A; LCSC Part C20917
R5, R14, R26: 10k; R_0603_1608Metric; LCSC Part C177337
R13: 220; R_0603_1608Metric; LCSC Part C1226
R19, R20: 22; R_0402_1005Metric; LCSC Part C174144
R21: 100k; R_0603_1608Metric_Pad0.98x0.95mm_HandSolder; LCSC Part C25803
R22, R23: 453k; C_0603_1608Metric; LCSC Part C25818
R24: 49.9k; C_0603_1608Metric; LCSC Part C23184
R28: 4.8K; R_0402_1005Metric; LCSC Part C174177
R33: 1k; R_0402_1005Metric; LCSC Part C173697
R34: 330; C_0402_1005Metric; LCSC Part C174156
R36: 1.2k; R_0402_1005Metric; LCSC Part C174261
Rpre1: 50ohm; RES-TH_BD9.0-L36.5-P40.50-D0.8; MPN EWWR0010J50R0T9; LCSC Part C349130
SW3: RESET1; KEY-SMD_KMR2XXGXXX; MPN KMR221GLFS; LCSC Part C72443
SW4: BOOT1; KEY-SMD_KMR2XXGXXX; MPN KMR221GLFS; LCSC Part C72443
TP4, TP10: GND; TestPoint_Pad_D2.0mm
TP8: 48VOUT; TestPoint_Pad_D2.0mm
TP9: 48VIN; TestPoint_Pad_D2.0mm
U1: ESP32-S3-WROOM-1; WIRELM-SMD_ESP32-S3-WROOM-1; LCSC Part C2913204
U2: 1-178136-3; 1-178136-3_TYC
U7: LM5013DDAR; ESOP-8_L4.9-W3.9-P1.27-LS6.0-BL-EP-1; MPN LM5013DDAR; LCSC Part C5383001

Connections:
+48VIN: C13.1, C14.1, C15.1, CN2.2 (+), TP9.1, U7.2 (VIN), U7.3 (EN/UVLO); also elsewhere on the board
+48VOUT: CN4.2, CN5.2, CN6.2, CN7.2, R28.2, Rpre1.1, TP8.1
/3V3: C3.1, C4.1, R5.1, R14.1, R34.1, U1.2 (3V3); also elsewhere on the board
/+12V: Ca1.1, Cout1.1, D11.1 (K), L3.2, R23.2, R36.2, U2.3; also elsewhere on the board
/D+OUT: R20.2; also elsewhere on the board
/D-OUT: R19.2; also elsewhere on the board
/GPIO0: C6.1, R14.2, SW4.3, SW4.4, U1.27 (IO0)
/GPIO1: J2.9, U1.39 (IO1)
/GPIO2: U1.38 (IO2); also elsewhere on the board
/GPIO4: U1.4 (IO4); also elsewhere on the board
/GPIO6: U1.6 (IO6); also elsewhere on the board
/GPIO15: U1.8 (IO15); also elsewhere on the board
/GPIO17: U1.10 (IO17); also elsewhere on the board
/GPIO38: R13.1, U1.31 (IO38)
/In-rush controller/+48VOUT: Rpre1.2; also elsewhere on the board
/LinOUT: Cbst1.1, Dsw1.1 (K), L3.1, R22.2, U7.8 (SW)
/RX: J2.3, U1.36 (RXD0)
/SCL: J2.7, U1.17 (IO9)
/SDA: J2.5, U1.12 (IO8)
/TX: J2.1, U1.37 (TXD0)
GND: C3.2, C4.2, C5.2, C6.2, C13.2, C14.2, C15.2, CN2.1 (-), CN2.3, CN2.4, CN4.1, CN5.1, CN6.1, CN7.1, Cout1.2, D9.1 (K), D16.1 (K), D17.1 (K), D19.1 (K), Dsw1.2 (A), H1.1, H2.1, H3.1, H4.1, J2.2, J2.4, J2.6, J2.8, J2.10, Q4.2 (S), R21.2, R24.1, R26.2, SW3.1, SW3.2, SW3.5, SW4.1, SW4.2, SW4.5, TP4.1, TP10.1, U1.1 (GND), U1.40 (GND), U1.41 (GND), U2.4, U2.5, U7.1 (GND), U7.9 (EP); also elsewhere on the board
unnamed: Ca1.2, Cb1.1, R22.1
unnamed: D9.2 (A), R28.1
unnamed: D11.2 (A), Q4.3 (D), R33.2, U2.2
unnamed: D16.2 (A), R36.1
unnamed: D17.2 (A), R34.2
unnamed: D19.2 (A), R33.1
unnamed: Q4.1 (G), R13.2, R26.1
unnamed: C5.1, R5.2, SW3.3, SW3.4, U1.3 (EN)
unnamed: R20.1, U1.14 (USB_D+)
unnamed: R19.1, U1.13 (USB_D-)
unnamed: Cbst1.2, U7.7 (BST)
unnamed: Cb1.2, R23.1, R24.2, U7.5 (FB)
unnamed: R21.1, U7.4 (RON)

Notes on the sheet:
Relay connector with low-side transistor
Pre-charge Switch
Mounting holes
DC-DC Buck 48V -> 12V
XT30 IN/OUT connectors
Relay connector

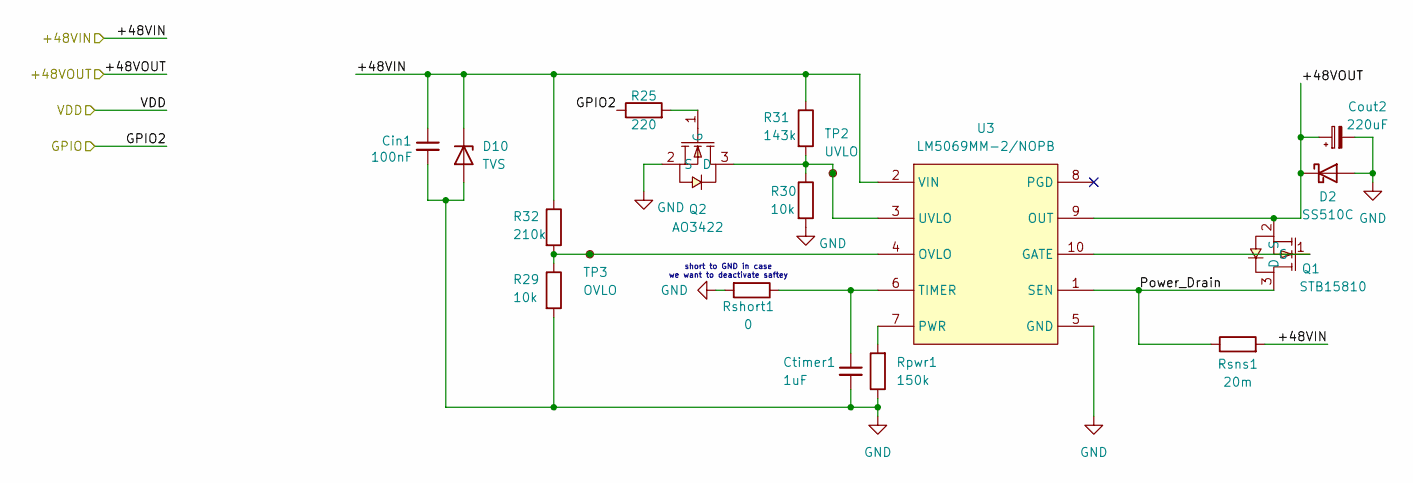
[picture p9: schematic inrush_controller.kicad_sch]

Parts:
Cin1: 100nF; C_1206_3216Metric; LCSC Part C1945
Cout2: 220uF; CAP-SMD_BD16.0-L17.0-W17.0-FD; LCSC Part C249883
Ctimer1: 1uF; C_1206_3216Metric; LCSC Part C13832
D2: SS510C; D_SMC; LCSC Part C19229
D10: TVS; D_SMB; LCSC Part C726833
Q1: STB15810; D2PAK_L10.2-W9.0-P5.08-LS16.9-BR; MPN STB15810; LCSC Part C620154
Q2: AO3422; SOT-23_L2.9-W1.3-P1.90-LS2.4-BR; MPN AO3422; LCSC Part C37130
R25: 220; R_0603_1608Metric; LCSC Part C1226
R29, R30: 10k; R_0603_1608Metric_Pad0.98x0.95mm_HandSolder; LCSC Part C25804
R31: 143k; R_0603_1608Metric_Pad0.98x0.95mm_HandSolder; LCSC Part C22877
R32: 210k; R_0603_1608Metric_Pad0.98x0.95mm_HandSolder; LCSC Part C22952
Rpwr1: 150k; R_0603_1608Metric; LCSC Part C22807
Rshort1: 0; R_0603_1608Metric_Pad0.98x0.95mm_HandSolder; LCSC Part C177335
Rsns1: 20m; RES-SMD_L6.4-W3.2-1; LCSC Part C915989
TP2: UVLO; TestPoint_Pad_D1.0mm
TP3: OVLO; TestPoint_Pad_D1.0mm
U3: LM5069MM-2/NOPB; VSSOP-10_L3.0-W3.0-P0.50-LS4.9-BL; MPN LM5069MM-2/NOPB; LCSC Part C111822

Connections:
+48VIN: Cin1.1, D10.1 (K), R31.1, R32.1, Rsns1.2, U3.2 (VIN); also elsewhere on the board
/GPIO2: R25.1; also elsewhere on the board
/In-rush controller/+48VOUT: Cout2.1, D2.1 (K), Q1.2 (S), U3.9 (OUT); also elsewhere on the board
/In-rush controller/Power_Drain: Q1.3 (D), Rsns1.1, U3.1 (SEN)
GND: Cin1.2, Cout2.2, Ctimer1.2, D2.2 (A), D10.2 (A), Q2.2 (S), R29.2, R30.2, Rpwr1.1, Rshort1.2, U3.5 (GND); also elsewhere on the board
unnamed: Q1.1 (G), U3.10 (GATE)
unnamed: Q2.3 (D), R30.1, R31.2, TP2.1, U3.3 (UVLO)
unnamed: Q2.1 (G), R25.2
unnamed: R29.1, R32.2, TP3.1, U3.4 (OVLO)
unnamed: Rpwr1.2, U3.7 (PWR)
unnamed: Ctimer1.1, Rshort1.1, U3.6 (TIMER)

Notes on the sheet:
short to GND in case we want to deactivate saftey

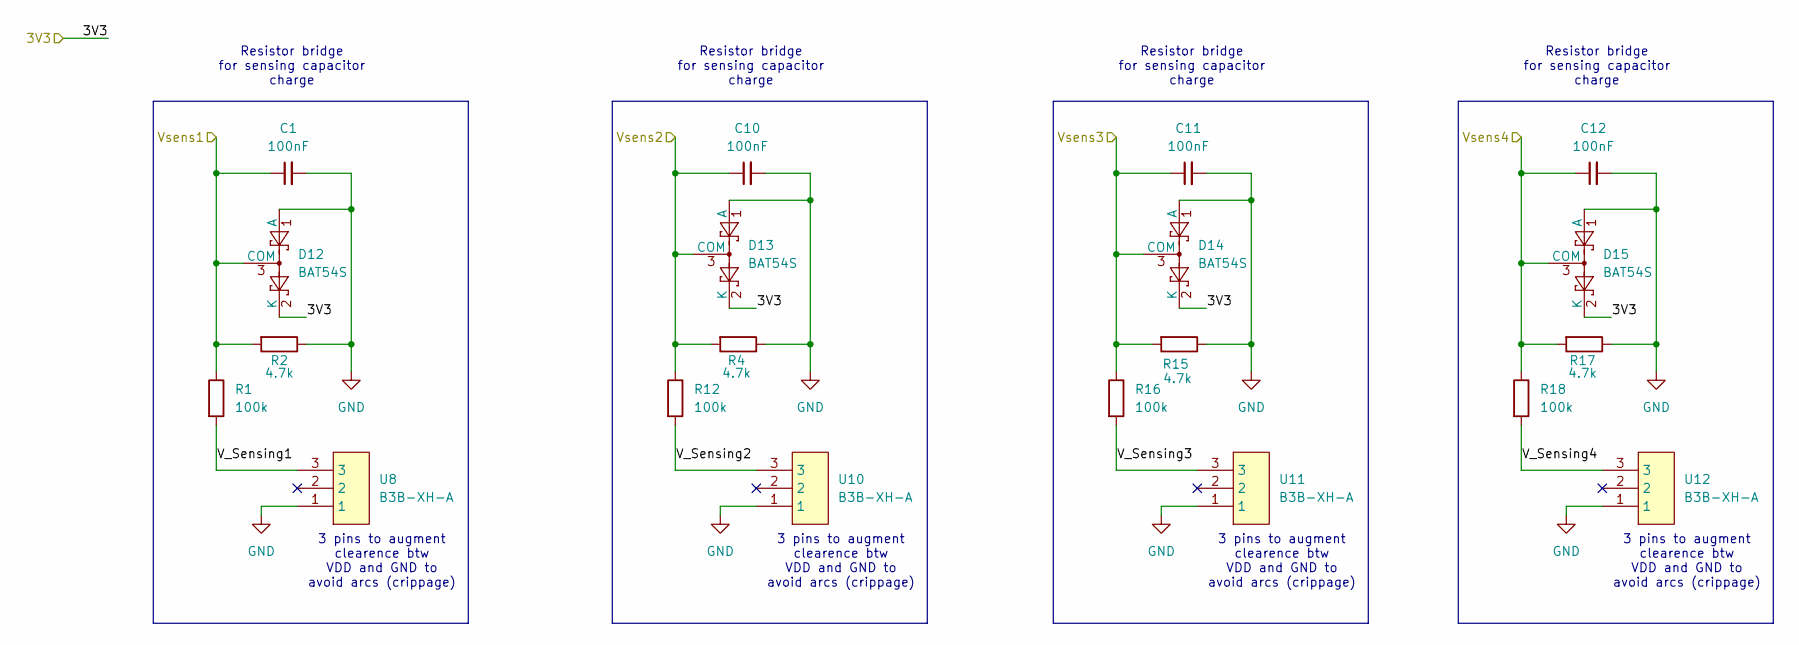
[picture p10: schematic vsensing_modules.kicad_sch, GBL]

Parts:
C1, C10, C11, C12: 100nF; C_0603_1608Metric; LCSC Part C1590
D12, D13, D14, D15: BAT54S; SOT-23; LCSC Part C83935
R1, R12, R16, R18: 100k; R_0603_1608Metric_Pad0.98x0.95mm_HandSolder; LCSC Part C25803
R2, R4, R15, R17: 4.7k; R_0603_1608Metric_Pad0.98x0.95mm_HandSolder; LCSC Part C177333
U8, U10, U11, U12: B3B-XH-A; CONN-TH_3P-P2.50_A2501WV2-3P; MPN B3B-XH-A(LF)(SN); LCSC Part C144394

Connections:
/3V3: D12.2 (K), D13.2 (K), D14.2 (K), D15.2 (K); also elsewhere on the board
/GPIO4: C1.1, D12.3 (COM), R1.1, R2.2; also elsewhere on the board
/GPIO6: C10.1, D13.3 (COM), R4.2, R12.1; also elsewhere on the board
/GPIO15: C11.1, D14.3 (COM), R15.2, R16.1; also elsewhere on the board
/GPIO17: C12.1, D15.3 (COM), R17.2, R18.1; also elsewhere on the board
/Voltage Sensing Modules/V_Sensing1: R1.2, U8.3
/Voltage Sensing Modules/V_Sensing2: R12.2, U10.3
/Voltage Sensing Modules/V_Sensing3: R16.2, U11.3
/Voltage Sensing Modules/V_Sensing4: R18.2, U12.3
GND: C1.2, C10.2, C11.2, C12.2, D12.1 (A), D13.1 (A), D14.1 (A), D15.1 (A), R2.1, R4.1, R15.1, R17.1, U8.1, U10.1, U11.1, U12.1; also elsewhere on the board

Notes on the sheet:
3 pins to augment clearence btw VDD and GND to avoid arcs (crippage)
Resistor bridge for sensing capacitor charge

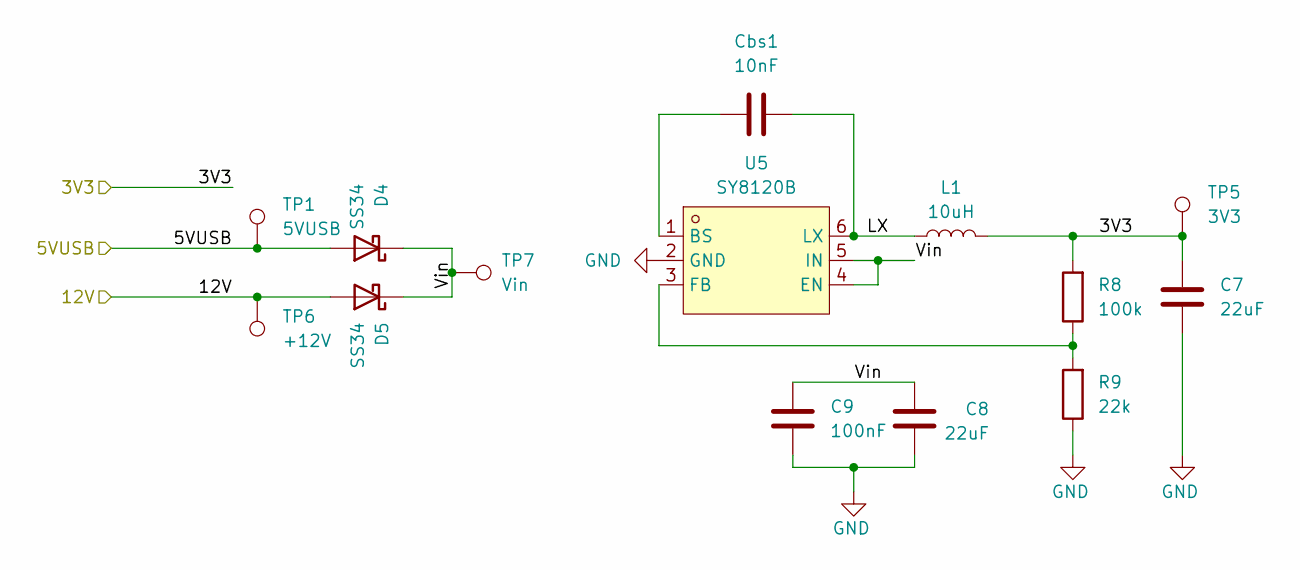
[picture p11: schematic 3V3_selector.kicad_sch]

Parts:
C7, C8: 22uF; C_1206_3216Metric_Pad1.33x1.80mm_HandSolder; LCSC Part C12891
C9: 100nF; C_0603_1608Metric_Pad1.08x0.95mm_HandSolder; LCSC Part C1590
Cbs1: 10nF; C_0603_1608Metric_Pad1.08x0.95mm_HandSolder; LCSC Part C53084460
D4, D5: SS34; D_SMA_Handsoldering; LCSC Part C8678
L1: 10uH; L_Cenker_CKCS5040; LCSC Part C354610
R8: 100k; R_0603_1608Metric_Pad0.98x0.95mm_HandSolder; LCSC Part C25803
R9: 22k; R_0603_1608Metric_Pad0.98x0.95mm_HandSolder; LCSC Part C177655
TP1: 5VUSB; TestPoint_Pad_D1.0mm
TP5: 3V3; TestPoint_Pad_D1.0mm
TP6: +12V; TestPoint_Pad_D2.0mm
TP7: Vin; TestPoint_Pad_D1.0mm
U5: SY8120B; SOT-23-6_L2.9-W1.6-P0.95-LS2.8-BL; MPN SY8120B; LCSC Part C5330397

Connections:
/3V3: C7.1, L1.2, R8.2, TP5.1; also elsewhere on the board
/3V3 Selector/LX: Cbs1.2, L1.1, U5.6 (LX)
/3V3 Selector/Vin: C8.1, C9.1, D4.1 (K), D5.1 (K), TP7.1, U5.4 (EN), U5.5 (IN)
/5VUSB: D4.2 (A), TP1.1; also elsewhere on the board
/+12V: D5.2 (A), TP6.1; also elsewhere on the board
GND: C7.2, C8.2, C9.2, R9.1, U5.2 (GND); also elsewhere on the board
unnamed: Cbs1.1, U5.1 (BS)
unnamed: R8.1, R9.2, U5.3 (FB)

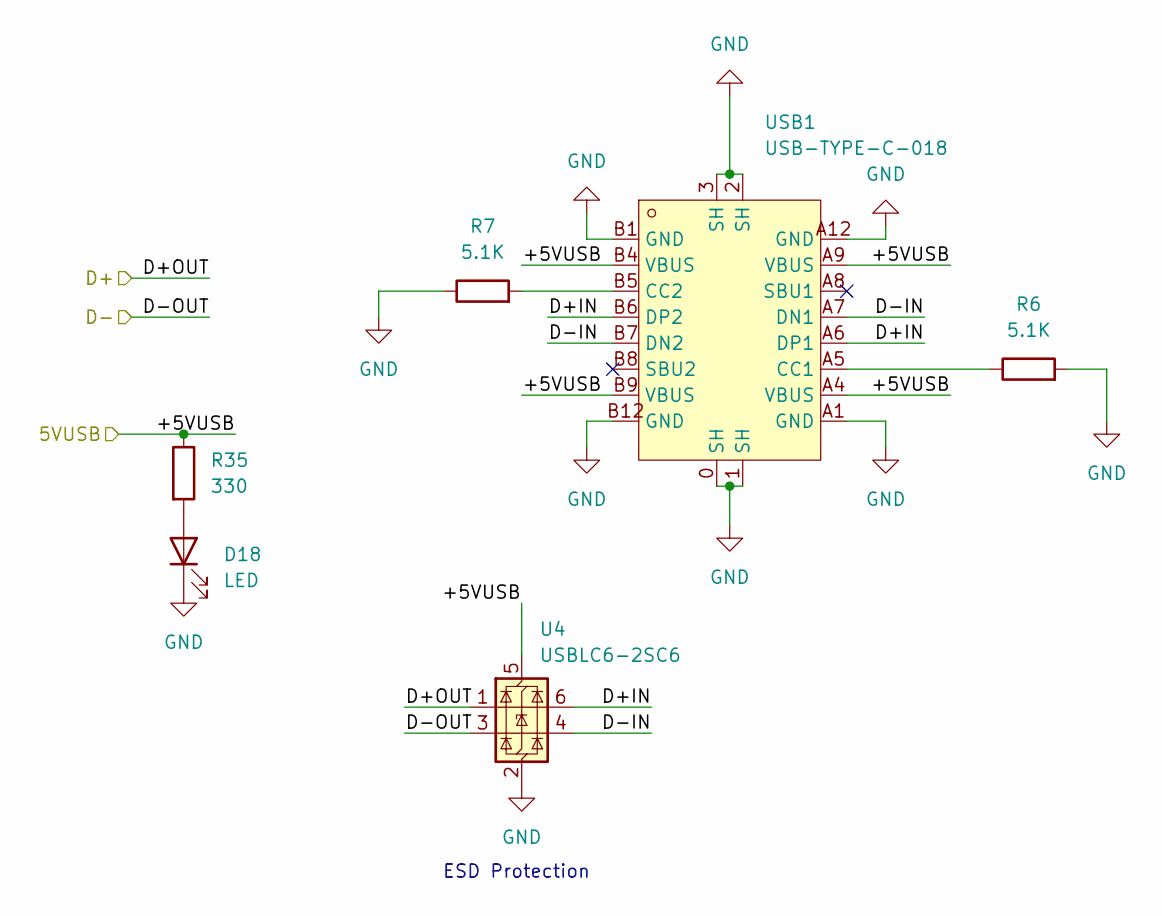
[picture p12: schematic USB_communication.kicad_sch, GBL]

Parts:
D18: LED; LED_0805_2012Metric_Pad1.15x1.40mm_HandSolder; LCSC Part C2293
R6, R7: 5.1K; LED_0603_1608Metric_Pad1.05x0.95mm_HandSolder; LCSC Part C23186
R35: 330; R_0402_1005Metric; LCSC Part C174156
U4: USBLC6-2SC6; SOT-23-6; LCSC Part C7519
USB1: USB-TYPE-C-018; USB-C_SMD-TYPE-C-31-M-12; MPN USB-TYPE-C-018; LCSC Part C2927038

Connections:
/5VUSB: R35.1, U4.5 (VBUS), USB1.A4 (VBUS), USB1.A9 (VBUS), USB1.B4 (VBUS), USB1.B9 (VBUS); also elsewhere on the board
/D+OUT: U4.1 (I/O1); also elsewhere on the board
/D-OUT: U4.3 (I/O2); also elsewhere on the board
/USB Communication/D+IN: U4.6 (I/O1), USB1.A6 (DP1), USB1.B6 (DP2)
/USB Communication/D-IN: U4.4 (I/O2), USB1.A7 (DN1), USB1.B7 (DN2)
GND: D18.1 (K), R6.2, R7.1, U4.2 (GND), USB1.0 (SH), USB1.1 (SH), USB1.2 (SH), USB1.3 (SH), USB1.A1 (GND), USB1.A12 (GND), USB1.B1 (GND), USB1.B12 (GND); also elsewhere on the board
unnamed: D18.2 (A), R35.2
unnamed: R6.1, USB1.A5 (CC1)
unnamed: R7.2, USB1.B5 (CC2)

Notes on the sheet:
ESD Protection

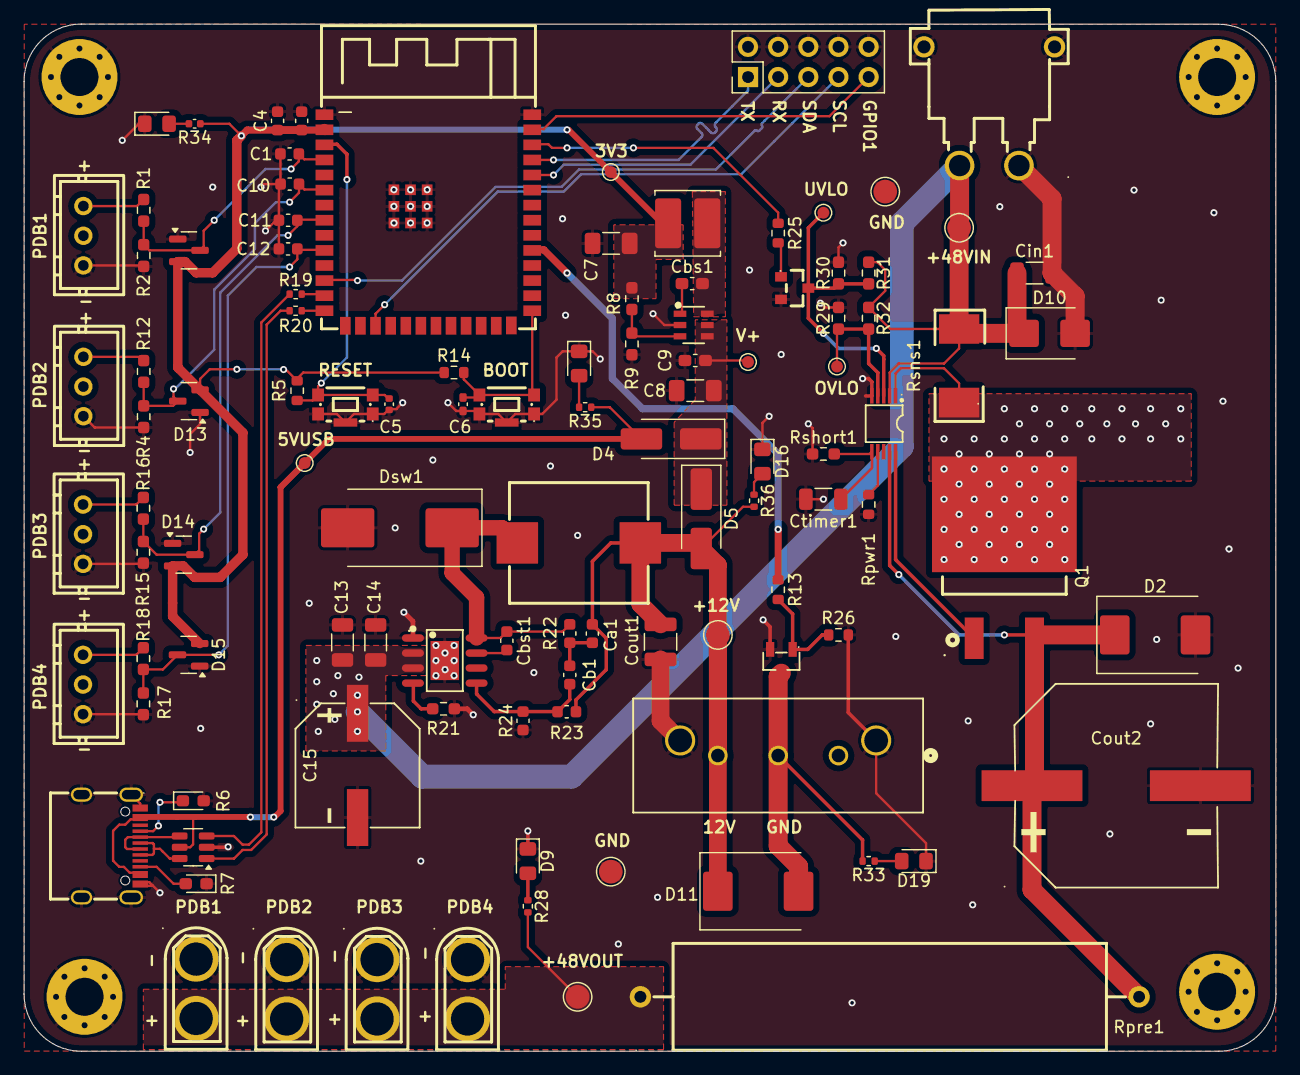
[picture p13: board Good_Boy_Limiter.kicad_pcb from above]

Board: 2 copper layers, 105.4 x 86.5 mm, 111 parts (0 on the bottom side), 55 nets.

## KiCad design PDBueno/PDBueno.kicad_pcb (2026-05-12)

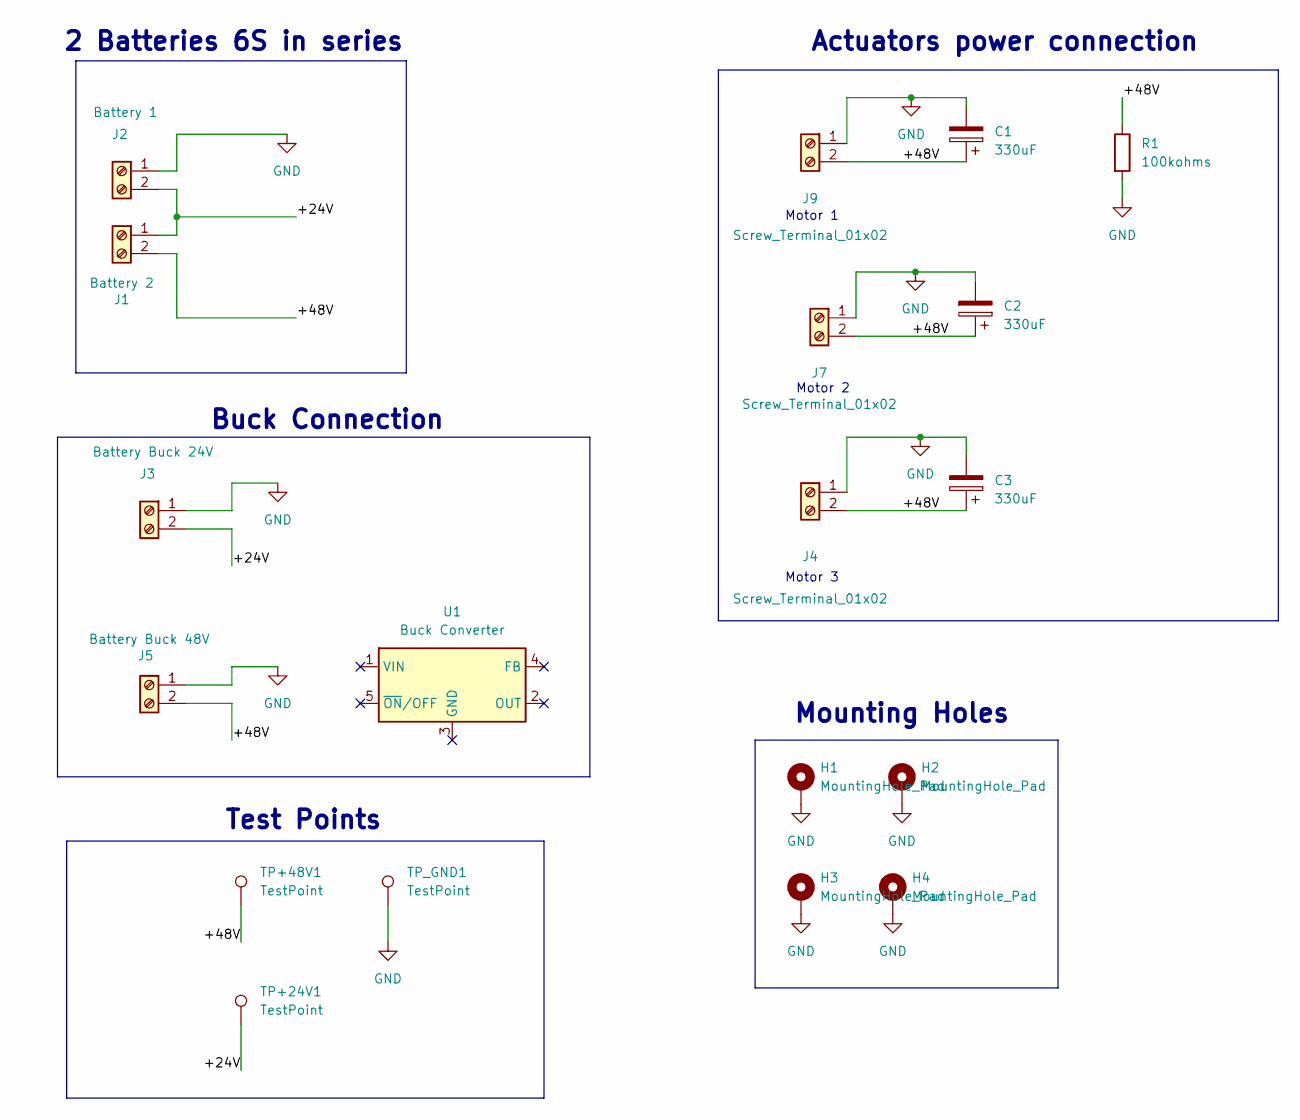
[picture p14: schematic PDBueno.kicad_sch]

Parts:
C1, C2, C3: 330uF; VZH331M2ATR-1816
H1, H2, H3, H4: MountingHole_Pad; MountingHole_3.2mm_M3_Pad_Via
J1: Battery 2; AMASS_XT90PW-M_1x02_P10.90mm_Horizontal
J2: Battery 1; AMASS_XT90PW-M_1x02_P10.90mm_Horizontal
J3: Battery Buck 24V; TerminalBlock_bornier-2_P5.08mm
J4, J7, J9: Screw_Terminal_01x02; AMASS_XT30PW-M_1x02_P2.50mm_Horizontal
J5: Battery Buck 48V; TerminalBlock_bornier-2_P5.08mm
R1: 100kohms; R_2512_6332Metric_Pad1.40x3.35mm_HandSolder; LCSC C25717
TP+24V1, TP+48V1: TestPoint; TestPoint_Pad_D4.0mm
TP_GND1: TestPoint; TestPoint_Pad_D4.0mm
U1: Buck Converter; BEC_Matek_12S_Pro

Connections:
/+24V: J1.1, J2.2, J3.2, TP+24V1.1
/+48V: C1.1, C2.1, C3.1, J1.2, J4.2, J5.2, J7.2, J9.2, R1.1, TP+48V1.1
GND: C1.2, C2.2, C3.2, H1.1, H2.1, H3.1, H4.1, J2.1, J3.1, J4.1, J5.1, J7.1, J9.1, R1.2, TP_GND1.1

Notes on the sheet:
Mounting Holes
Actuators power connection
2 Batteries 6S in series
Motor 1
Test Points
Motor 2
Buck Connection
Motor 3

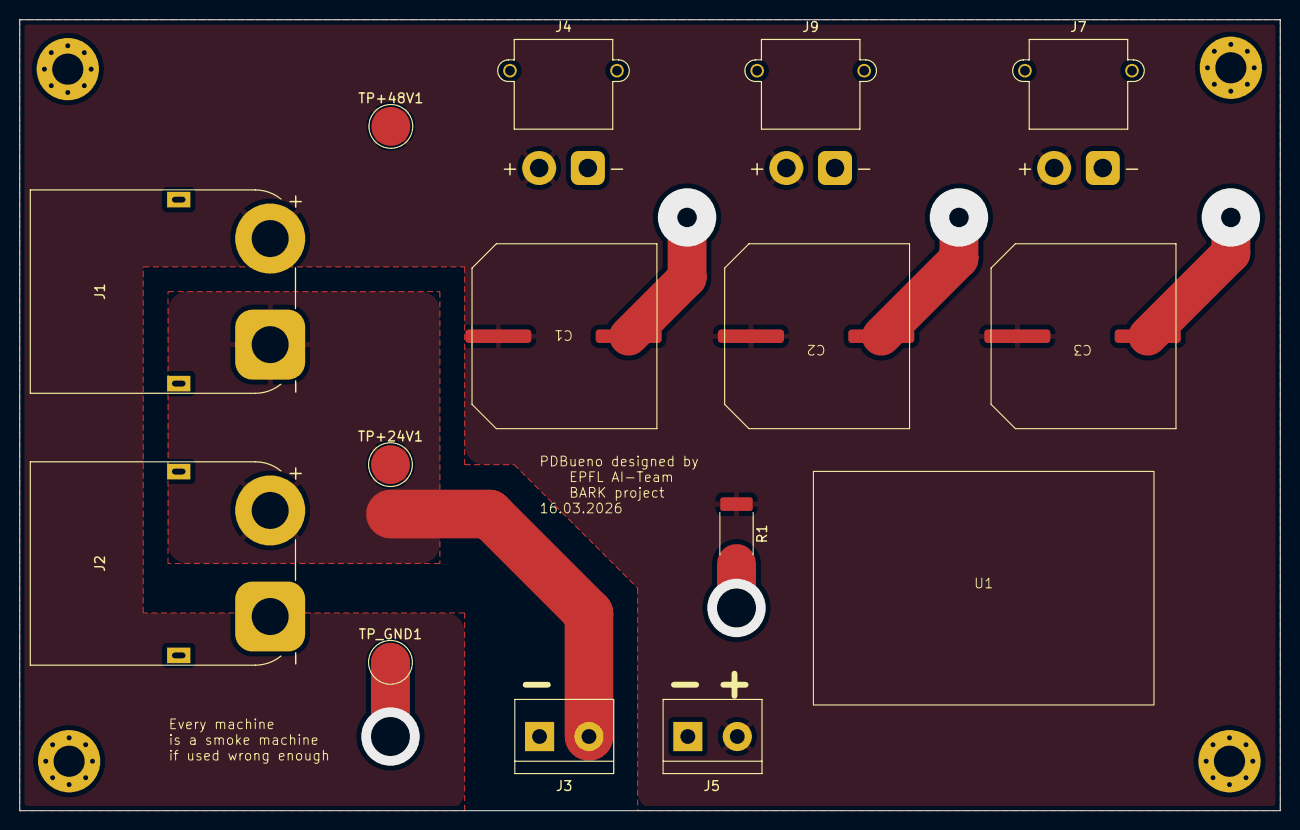
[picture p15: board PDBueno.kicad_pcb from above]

Board: 2 copper layers, 129.5 x 81.3 mm, 19 parts (0 on the bottom side), 3 nets.

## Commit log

2026-03-07 Added empty base files for KiCad
    [BYTE_Electronics.kicad_pcb, BYTE_Electronics.kicad_sch]
2026-03-10 copie de mon projet kicad
    [BYTE_Electronics.kicad_sch]
2026-03-10 Footprint added and minor changes
    [BYTE_Electronics.kicad_sch]
2026-03-14 Avencement du pcb avec connexions
    [BYTE_Electronics.kicad_pcb, BYTE_Electronics.kicad_sch]
2026-03-14 PDByte added
    [PDByte.kicad_pcb, PDByte.kicad_sch]
2026-03-14 Added PDbyte at right place
    [PDByte.kicad_pcb, PDByte.kicad_sch]
2026-03-14 first changes for PDByte
    [PDByte.kicad_pcb, PDByte.kicad_sch]
2026-03-14 Added footprint for 330uF capa
2026-03-14 added footprint to compo exept switch and Buck
    [BYTE_Electronics.kicad_sch]
2026-03-14 added folder for PCBueno
    [BYTE_Electronics.kicad_pcb, BYTE_Electronics.kicad_sch]
2026-03-14 PCB routing
    [BYTE_Electronics.kicad_pcb, BYTE_Electronics.kicad_sch]
2026-03-16 Renamed PDBueno project files and added SPIne project
    [PDBueno.kicad_pcb, PDBueno.kicad_sch, SPIne.kicad_pcb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]
2026-03-16 added some basic connection on SPIne
    [SPIne.kicad_sch]
2026-03-16 Added vias to properly connect capacitors to GND
    [PDBueno.kicad_pcb]
2026-03-16 50th copper pour
    [PDBueno.kicad_pcb, PDBueno.kicad_sch]
2026-03-16 updates updates updates...
    [PDBueno.kicad_pcb, PDBueno.kicad_sch]
2026-03-17 corrected Electrical scheme with conventions
    [PDByte.kicad_sch]
2026-04-14 Added library from JLCPCB, and GBL folder
    [Good_Boy_Limiter.kicad_pcb, Good_Boy_Limiter.kicad_sch]
2026-04-14 Added schottky and Inductor for DC-DC converter
    [Footprint_PB_Byte.PcbLib, Good_Boy_Limiter.kicad_pcb, Good_Boy_Limiter.kicad_sch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]
2026-04-15 FIX: Added capacitors for Buck
    [Good_Boy_Limiter.kicad_pcb, Good_Boy_Limiter.kicad_sch]
2026-04-17 Added a lot of stuff, sowwy
    [12V_to_3V3.kicad_sch, Good_Boy_Limiter.kicad_pcb, Good_Boy_Limiter.kicad_sch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]
2026-04-17 Added some footprints
    [12V_to_3V3.kicad_sch, Good_Boy_Limiter.kicad_pcb, Good_Boy_Limiter.kicad_sch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]
2026-04-18 Added more footprints
    [Good_Boy_Limiter.kicad_pcb, Good_Boy_Limiter.kicad_sch]
2026-04-18 Added all footprints
    [12V_to_3V3.kicad_sch, 3V3_selector.kicad_sch, Good_Boy_Limiter.kicad_pcb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]
2026-04-19 Added mounting holes and test points
    [3V3_selector.kicad_sch, Good_Boy_Limiter.kicad_sch]
2026-04-19 started some routing
    [Good_Boy_Limiter.kicad_pcb, Good_Boy_Limiter.kicad_sch]
2026-04-19 Added PWR-FLag for ERC check
    [Good_Boy_Limiter.kicad_sch]
2026-04-20 fix: added 4 voltage sensing modules to measure all the 4 PDBs
    [Good_Boy_Limiter.kicad_pcb, Good_Boy_Limiter.kicad_sch, vsensing_modules.kicad_sch]
2026-04-20 Routing update
    [Good_Boy_Limiter.kicad_pcb, Good_Boy_Limiter.kicad_sch, USB_communication.kicad_sch]
2026-04-21 Updated routing
    [Good_Boy_Limiter.kicad_pcb, USB_communication.kicad_sch]
2026-04-21 More update on routing
    [3V3_selector.kicad_sch, Good_Boy_Limiter.kicad_pcb, Good_Boy_Limiter.kicad_sch]
2026-04-21 Added xt30 adn routed, ready for revision
    [3V3_selector.kicad_sch, Good_Boy_Limiter.kicad_pcb, Good_Boy_Limiter.kicad_sch]
2026-04-29 Finished e-scheme
    [3V3_selector.kicad_sch, Good_Boy_Limiter.kicad_pcb, Good_Boy_Limiter.kicad_sch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]
2026-04-29 started routing
    [3V3_selector.kicad_sch, Good_Boy_Limiter.kicad_pcb, Good_Boy_Limiter.kicad_sch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]
2026-05-03 routing finished
    [3V3_selector.kicad_sch, Good_Boy_Limiter.kicad_pcb, Good_Boy_Limiter.kicad_sch]
2026-05-03 DRC fixes
    [Good_Boy_Limiter-B_Cu.gbr, Good_Boy_Limiter-B_Mask.gbr, Good_Boy_Limiter-B_Paste.gbr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]
2026-05-05 Added first documentation for GBL
    [Good_Boy_Limiter-B_Cu.gbr, Good_Boy_Limiter-B_Mask.gbr, Good_Boy_Limiter-B_Paste.gbr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]
2026-05-05 Added pictures and title page
    [Good_Boy_Limiter.kicad_pcb, Good_Boy_Limiter.kicad_sch, inrush_controller.kicad_sch]
2026-05-06 Documentation update
    [Good_Boy_Limiter.kicad_pcb]
2026-05-08 added 3Ds and added more output fore PDBs
    [Good_Boy_Limiter.kicad_pcb, Good_Boy_Limiter.kicad_sch]
2026-05-08 e-scheme update
    [Good_Boy_Limiter.kicad_sch]
2026-05-08 Added orange led
    [Good_Boy_Limiter.kicad_pcb, Good_Boy_Limiter.kicad_sch]
2026-05-08 Folder cleaning
    [12V_to_3V3.kicad_sch, LED_Alimentation_indicator.kicad_sch, untitled.kicad_sch]
2026-05-11 Solved DRC and ERC
    [Good_Boy_Limiter.kicad_pcb, Good_Boy_Limiter.kicad_sch, USB_communication.kicad_sch]
2026-05-12 fix: removed copper plate in antenna area
    [Good_Boy_Limiter.kicad_pcb]
2026-05-12 feat: added AIT logo
    [Good_Boy_Limiter.kicad_pcb]
2026-10-03 feat: added general power scheme and remouved useless folders
    [3V3_selector.kicad_sch, BYTE_Power_Scheme.kicad_pcb, BYTE_Power_Scheme.kicad_sch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]
2026-11-11 feat: GBL pre-charge firmware (production + debug)
    - Replace the hello_world template with GBL_Firmware (standard ESP-IDF layout)
    - gbl_hw component: Q1/relay control, monitored pre-charge, controlled shutdown,
    Rpre1 watchdog and cooldown, PDB voltage sensing, power switch input
    - Production state machine on the main power switch, debug console
    - menuconfig: application selection and LiPo pack (6S/12S/13S) thresholds
    - sdkconfig.defaults and README
